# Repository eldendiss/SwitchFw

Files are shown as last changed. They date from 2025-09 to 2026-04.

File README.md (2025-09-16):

# AVR HV Flyback & Geiger-Müller Tube Detector

A high-voltage flyback power supply controller with integrated Geiger-Müller tube detector, featuring 4 selectable voltage ranges and I²C communication interface.

## Overview
This project implements an AVR-based controller for a high-voltage flyback power supply system designed for Geiger-Müller tube applications. The system provides precise voltage regulation across 4 selectable ranges, pulse counting capabilities, and remote control via I²C communication.

### Key Features
- High-Voltage Flyback Control: PWM-controlled flyback transformer with feedback regulation
- 4 Voltage Ranges: Relay-switched voltage ranges for different GM tube requirements
- Geiger Pulse Detection: Hardware pulse counting with debouncing and filtering
- I²C Slave Interface: Remote configuration and monitoring via I²C protocol
- Fault Protection: Overvoltage detection, current limiting, and safety shutdowns
- EEPROM Storage: Persistent configuration storage with wear leveling
- Status Indication: LED indicators for system status and fault conditions

## Hardware Architecture
### Core Components
- MCU: ATmega328P (TQFP-32) running at up to 20MHz
- Power Stage: IRF540N N-channel MOSFET with TC4420 gate driver
- Voltage Reference: LM4040 2.5V precision shunt regulator
- Amplifiers: LM321 operational amplifiers for signal conditioning
- Protection: SMAJ150A transient voltage suppressor
- Power Supply: LM317 adjustable linear regulator for 5V rail

### Voltage Range Switching
Four relay-controlled voltage ranges provide flexibility for different GM tube types.

## Pin Configuration
### I²C Communication
- **SDA**: PC4
- **SCL**: PC5
- **Default address**: 0x2A

### Control Outputs
- **PWM**: PB1 - Flyback MOSFET
- **Range Relays**: PD4, PD5, PB6, PB7 - Voltage range selection
- **Status LEDs**: PC2, PC3 - System status indication

### Analog Inputs
- **Feedback**: PC0 - Voltage feedback from HV output
- **Current Sense**: PC1 - Shunt current measurement

### Digital Inputs
- **Enable**: External enable signal
- **Range Select**: Hardware range selection inputs

### Programming interface
- **ISP header**: MISO (PB4), MOSI (PB3), SCK (PB5), RESET (PC6)

## Firmware Features

### PWM Control System
- **Frequency**: 31.25 kHz (configurable)
- **Resolution**: 8-bit (256 steps)
- **Duty Cycle Range**: 0-20% (safety limited)
- **Control Loop**: 1 kHz PI controller with derivative feedback

### Voltage Regulation
- **Feedback**: 10-bit ADC with 8× averaging
- **Setpoint Resolution**: ~1V steps (depending on range)
- **Regulation Accuracy**: ±1% typical
- **Response Time**: <100ms to 90% of setpoint
### Fault Protection
- **Overvoltage**: Programmable trip and clear thresholds per range
- **Overcurrent**: Hardware comparator with cycle-by-cycle limiting
- **Watchdog**: Hardware and software watchdog protection
### Geiger Pulse Detection
- **Input Conditioning**: Hardware debouncing and noise filtering
- **Count Resolution**: 32-bit counters
- **Rate Calculation**: CPS (counts per second) and CPM (counts per minute)
- **Dead Time Compensation:** Configurable dead time correction

## I²C Protocol
### Register Map
|Address |Name |Type |Decsription |
|---|---|---|---|
|0x00-0x01  |FB_SET_CNT |R/W |Active feedback setpoint (counts)  |
|0x02-0x03  |FB_OV_TRIP_CNT |R/W |Active overvoltage trip threshold  |
|0x04-0x05  |FB_OV_CLEAR_CNT |R/W |Active overvoltage clear threshold |
|0x06-0x0D  |FB_SET_CNT_TAB |R/W |Per-range setpoint table (4×u16) |
|0x0E-0x15  |FB_OV_TRIP_TAB |R/W |Per-range OV trip table (4×u16) |
|0x16-0x1D  |FB_OV_CLEAR_TAB |R/W |Per-range OV clear table (4×u16) |
|0x20 |RANGE_REQ |W |Range selection request (0-3) |
|0x21 |RANGE_SRC |R/W |Range source (0=HW, 1=I2C, 2=AUTO) |
|0x40 |CMD |W |Command register |
|0x50-0x57  |STATUS |R |8-byte status block |

### Commands (0x40)
- **0x01**: Save configuration to EEPROM
- **0x02**: Reset controller to PRECHARGE state

### Status Block (0x50-0x57)

```c
struct {
    uint8_t  run_state;     // Current controller state
    uint8_t  fault_code;    // Active fault conditions
    uint16_t fb_counts;     // Current feedback (ADC counts)
    int16_t  dcounts;       // Feedback derivative
    uint8_t  active_range;  // Currently selected range (0-3)
    uint8_t  range_busy;    // Range switching in progress
} status;
```

## Software Architecture
### Control States
- **PRECHARGE**: Soft-start phase with fixed low duty cycle
- **PI_CONTROL**: Closed-loop voltage regulation
- **PFM_HOLD**: Closed-loop voltage regulation
- **FAULT**: Safe shutdown with fault indication

### Main Control Loop (1 kHz)
1. **ADC Sampling**: Read feedback voltage with 8× averaging
2. **Fault Detection**: Check overvoltage and overcurrent conditions
3. **PI Controller**: Calculate required PWM duty cycle
4. **Range Management**: Handle relay switching with stability checks
5. **Pulse Counting**: Process Geiger tube pulses
6. **I²C Service**: Handle configuration updates and status requests

### Safety Features
- **Duty Cycle Limiting**: Hardware and software duty cycle caps
- **Fault Latching**: Persistent fault states requiring explicit reset
- **Graceful Degradation**: Automatic power reduction under fault conditions
- **Watchdog Protection**: System reset on firmware lockup

## Configuration and Calibration
### Voltage Scaling
The system uses a configurable voltage divider to scale HV output to ADC range:
- **Full Scale**: 1077.5V = 1023 ADC counts (default)
- **Resolution**: ~1.05V per ADC count
- **Calibration**: Adjustable via I²C configuration

### Range-Specific Parameters
Each voltage range has independent configuration:

- **Setpoint**: Target voltage in ADC counts
- **OV Trip**: Overvoltage fault threshold
- **OV Clear**: Overvoltage recovery threshold

### EEPROM Layout
Configuration is stored in EEPROM with wear leveling:

- **Slot Size**: 128 bytes per configuration
- **Wear Leveling**: Automatic slot rotation
- **CRC Protection**: 16-bit CRC for data integrity
- **Default Recovery**: Automatic fallback to safe defaults

## Safety Considerations
### Electrical Safety
- **High Voltage Warning**: Output voltages up to 1000V present electrocution hazard
- **Isolation**: Maintain proper isolation between HV and control circuits
- **Interlocks**: Implement appropriate safety interlocks for enclosure access
- ****:

### Operational Safety
- **Fault Monitoring**: Always monitor fault status during operation
- **Emergency Shutdown**: Implement external emergency stop capability
- **Thermal Management**: Ensure adequate cooling for power components

## Troubleshooting

### Common Issues
#### No HV Output
- Check enable signal
- Verify PWM generation on PB1
- Check MOSFET gate drive
- Verify transformer connections

#### I²C Communication Errors
- Verify bus pull-up resistors
- Check address conflicts
- Monitor bus timing
- Verify power supply stability

## Development and Programming
### Build Environment
- **Toolchain**: AVR-GCC with AVR-LibC
- **IDE**: PlatformIO
- **Programmer**: ISP programmer (USBasp, AVR Dragon, etc.)

## License
This project is licensed under a **Non-Commercial License**.  
- ✅ Free for personal, educational, and research use.  
- ❌ Commercial use, redistribution for profit, or inclusion in commercial products is prohibited without written permission.  
See [LICENSE](./LICENSE) for details.

⚠️ WARNING: This device generates potentially lethal high voltages. Only qualified personnel should operate, maintain, or modify this equipment. Always follow proper safety procedures when working with high-voltage systems.

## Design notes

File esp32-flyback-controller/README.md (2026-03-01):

# Flyback PSU & Geiger Counter ESP-IDF Driver

ESP-IDF drivers for:
- an **AVR flyback HV PSU** (I²C, 4 ranges, status/commands), and
- a **Geiger pulse counter** using the ESP32 RMT RX peripheral.

Works on ESP-IDF v5+.

## Overview

- **Flyback PSU driver (`flyback_psu`)**: Configure per-range setpoints/OV thresholds, select ranges (HW/I²C/AUTO), read 8-byte status, and issue SAVE/RESET commands. Counts↔volts helpers included.
- **Geiger counter driver (`geiger_counter`**: Counts tube pulses with RMT RX. Filters glitches by minimum pulse width. Provides **CPS, CPM (rolling 60 s)**, and **total**. Thread-safe getters.
- **Example application (`main`)**: Demonstrates how to initialize and use both drivers together, cycling through PSU voltage ranges and logging Geiger counts.

---

## Features

### Flyback PSU

- I²C master init/reuse, configurable clock.
- Range source control: HW / I²C / AUTO.
- Program per-range set, OV trip, OV clear (counts or volts).
- Read compact STATUS: run_state, fault_code, fb_counts, dcounts, active_range, busy.
- SAVE_CONFIG, RESET_CTRL commands.
- Helpers: volts↔counts, set profiles, wait-until-idle.

### Geiger Counter

- RMT RX capture with **min pulse width** filter (ns).
- Configurable **active level** (high/low), **resolution** (Hz), buffer size.
- Thread-safe **get_total(), get_cps(), get_cpm()**.
- Internal task processes RX buffers (zero-copy on symbols).

---

## Hardware Requirements

- ESP32/ESP32-Sx/Cx with ESP-IDF v5+
- I²C wiring to AVR PSU at 0x2A (pull-ups required)
- Tube pulse output routed to an ESP32 GPIO
- CMake build (component-based)

---

## Getting Started

### 1. Clone and Setup ESP-IDF

Follow the official ESP-IDF setup guide:

[ESP-IDF Programming Guide](https://docs.espressif.com/projects/esp-idf/en/latest/esp32/get-started/)

### 2. Add Flyback PSU and Geiger Counter Drivers

Include the provided driver source files (`flyback_psu.h/c`, `geiger_counter.h/c`) in your project.

### 3. Example Application

The example demonstrates:

- Initializing the flyback PSU over I²C.
- Setting voltage setpoints and overvoltage thresholds.
- Forcing I²C control of the active voltage range.
- Initializing the Geiger counter on a GPIO pin.
- Cycling through the four voltage ranges, holding each for 60 seconds.
- Logging PSU status and Geiger counts every second.

---

## API Usage

### Flyback PSU

#### Initialization

```c
flyback_psu_t psu;
ESP_ERROR_CHECK(flyback_psu_init(&psu, I2C_NUM_0, SDA_GPIO, SCL_GPIO, 10000 /* 10 kHz */, 0x2A));
flyback_psu_set_fullscale(&psu, 1077.5f); // 1023 counts == 1077.5 V
```

#### Set Range Source to I²C

```c
ESP_ERROR_CHECK(flyback_psu_set_range_source(&psu,  FLYBACK_RANGE_SRC_I2C));
```

#### Set Voltage Setpoints (volts)

```c
const float V[4] = {200, 500, 700, 900};
uint16_t C[4];
for (int i=0;i<4;i++) C[i] = flyback_psu_volts_to_counts(&psu, V[i]);
ESP_ERROR_CHECK(flyback_psu_set_table_counts4(&psu, C));

// Trip/Clear @ +10% / +5%
for (int i=0;i<4;i++){
  ESP_ERROR_CHECK(flyback_psu_set_trip_counts(&psu,  i,
     flyback_psu_volts_to_counts(&psu, V[i]*1.10f)));
  ESP_ERROR_CHECK(flyback_psu_set_clear_counts(&psu, i,
     flyback_psu_volts_to_counts(&psu, V[i]*1.05f)));
}
// Optional: ESP_ERROR_CHECK(flyback_psu_send_command(&psu, FLYBACK_CMD_SAVE_CONFIG));
```

#### Start the Geiger counter
```c
geiger_counter_t gc = {0};
ESP_ERROR_CHECK(geiger_counter_start(&gc,
    GPIO_NUM_4,          // pulse input GPIO
    true,                // active-high pulses
    20000000,            // 20 MHz resolution (50 ns tick)
    1000,                // ≥1 µs min pulse width
    2048));              // RX symbol buffer

```

#### Select Active Range

```c
ESP_ERROR_CHECK(flyback_psu_select_range(&psu, range_index));
ESP_ERROR_CHECK(flyback_psu_wait_idle(&psu, 3000, 10)); // wait for relay switch
```

#### Read Status

```c
flyback_psu_status_t status;
if (flyback_psu_read_status(&psu, &status) == ESP_OK) {
    float feedback_volts = flyback_psu_counts_to_volts(&psu, status.fb_counts);
    // Use status fields as needed
    ESP_LOGI("PSU","st=%u fault=%u fb=%u(%.1fV) d=%d r=%u busy=%u",
             s.run_state, s.fault_code, s.fb_counts, v, (int)s.dcounts,
             s.active_range, s.range_busy);
}
ESP_LOGI("GEIGER","CPS=%.1f CPM=%.1f Total=%llu",
           geiger_counter_get_cps(&gc),
           geiger_counter_get_cpm(&gc),
           (unsigned long long)geiger_counter_get_total(&gc));
  vTaskDelay(pdMS_TO_TICKS(1000));
```

### Geiger Counter

#### Initialization
```c
static geiger_counter_t gc;
ESP_ERROR_CHECK(geiger_counter_start(&gc, TUBE_GPIO, TUBE_ACTIVE_HIGH, 20000000, 1000, 2048));
```

#### Get Counts

```c
float cps = geiger_counter_get_cps(&gc);   // Counts per second (delta)
float cpm = geiger_counter_get_cpm(&gc);   // Counts per minute (rolling 60s)
uint64_t total = geiger_counter_get_total(&gc); // Total counts since start
```

#### Stop Counter
```c
ESP_ERROR_CHECK(geiger_counter_stop(&gc));
```

## Example output
```
I (1234) example: Selecting range 0 -> target voltage ~200.0 V (counts=190)
I (1235) example: PSU status: state=1 fault=0 fb_counts=185 (~198.5 V) dcounts=0 active_range=0 busy=0
I (1235) GEIGER: Counts: CPS=5.0  CPM=300.0  Total=1500
...
```

## Notes & Best Practices
- **I²C speed:** Start at **10 kHz** (robust on long harnesses). If wiring is short/clean, 100–400 kHz is fine.
- **Range arbitration:**
    - `AUTO`: hardware pins control until the first I²C request, then I²C takes over.
    - If your front panel uses the HW pins, prefer AUTO so remote control can still take over.
- **STATUS → volts:** `V ≈ fb_counts * (fullscale / 1023.0)`, default fullscale **1077.5 V**.
- **RMT sizing:**
    - `resolution_hz = 20 MHz` gives 50 ns ticks; good for 2–5 µs pulses.
    - `min_pulse_ns`: start with 1000 ns (rejects narrow noise).
    - `buf_symbols`: 1024–2048 typical; increase if you expect high CPM or bursts.
- **Threading**:
    - RMT RX runs a task; getters use a mutex; safe from multiple tasks.
    - Avoid calling `geiger_counter_stop` from ISR context.

- The Geiger counter uses a dedicated FreeRTOS task and RMT peripheral; ensure sufficient stack size and priority.
- Use flyback_psu_send_command() to save configuration to EEPROM or reset the controller if needed.
- The example cycles through all four voltage ranges, holding each for 60 seconds, printing status and counts every second.

## Troubleshooting
- **I²C timeouts**
    - Check address `0x2A`, pull-ups, and grounds. Drop bus to **10 kHz** first.
- **STATUS never idle (`busy=1`)**
    - Mechanical relays need time; ensure `flyback_psu_wait_idle()` poll interval ≥ 10 ms and timeout ≥ 3 s.
- **OV faults**
    - Trip/clear thresholds too tight for the measured divider scaling. Re-measure HV and adjust counts.
- **Few/no counts**
    - Pulse polarity mismatch (`active_high`). Increase `min_pulse_ns` if noise, decrease if valid pulses are ~1–2 µs but get filtered.

## License
This project is licensed under a **Non-Commercial License**.  
- ✅ Free for personal, educational, and research use.  
- ❌ Commercial use, redistribution for profit, or inclusion in commercial products is prohibited without written permission.  
See [LICENSE](./LICENSE) for details.

## References
- [ESP-IDF Programming Guide](https://docs.espressif.com/projects/esp-idf/en/latest/esp32/)
- [ESP32 RMT Peripheral](https://docs.espressif.com/projects/esp-idf/en/latest/esp32/api-reference/peripherals/rmt.html)
- AVR flyback PSU firmware documentation

## Notes
Lite: SDA=21, SCL=22
Big: SDA=22, SCL=21

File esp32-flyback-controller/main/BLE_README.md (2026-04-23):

# RaSens BLE Documentation

## UUID

We use 128-bit Vendor UUID - 16 bit UUIDs are reserved for SIG approved devices.

Device base UUID is assigned at random per device type, except for last 2 bytes. For example:
- Base: ```704d43a7-dd07-49f1-9818-8ca1364e0000```

Each service characteristic uses the last 2 bytes for identification. For simplicity in this documetation, we will only specify the last 2 bytes appended to base UUID, e.g. ```...0001``` translates to ```704d43a7-dd07-49f1-9818-8ca1364e0001```

```
0000 - Base UUID
    0010 - Provisioning Service
        0011 - SSID Characteristics
        0012 - Password Characteristics
        0013 - MQTT Server Characteristics
        0014 - MQTT Port Characteristics
        0015 - Access Token Characteristics
        0016 - Command Characteristics
        0017 - Status Characteristics
    0020 - Configuration Service
        0021 - Interval Characteristics    
        0022 - Range Characteristics 
        0023 - Set Voltage Characteristics      
        0024 - Coefficients Characteristics 
```

Each characteristics also has permissions and properties, see BLE documentation for more info about these. There is also an option of encrypted read/write, which allow operation only after devices are bonded.
Test

Defined services (later will be extended further):

---
### Provisioning Service

- Provision wifi credentials / MQTT server
- Provisioning is confirmed by writing a command
- Allows notifications on status
- UUID: ```0010```

#### SSID
- UUID: ```0011```
- Properties: Write
- Permissions: currently only W, in the future consider encrypted W
- Do not expose as Read in production
- Data: UTF-8, max 32 bytes

#### Password
- UUID: ```0012```
- Properties: Write
- Permissions: currently only W, in the future consider encrypted W
- Do not expose as Read in production
- Data: UTF-8, max 63 bytes

#### MQTT Server
- UUID: ```0013```
- Properties: Read/Write
- Permissions: R/W
- Data: UTF-8, max. 63 bytes

#### MQTT Port
- UUID: ```0014```
- Properties: Read/Write
- Permissions: R/W
- Data: uint16

#### Access Token
- UUID: ```0015```
- Properties: Write
- Permissions: currently only W, in the future consider encrypted W
- Data: UTF-8, max. 24 bytes

#### Apply/Command
- UUID: ```0016```
- Properties: Write
- Permissions: W
- Data: 1 byte
    - ```0x01``` - Apply (attempt Wifi+MQTT connect)
    - ```0x02``` - Disconnect / Clear
    - ```0x03``` - Save (do not connect instantly)

#### Status
- UUID: ```0017```
- Properties: Read + Notify
- Permissions: R
- Data: 8 byte array
    - ```device_status```
    - ```wifi_status```
    - ```mqtt_status```
    - ```err_code```
    - ```wifi_rssi```
    - ```reserved[3]```

---
### Configuration Service
- Set up device parameters
- UUID: ```0020```

#### Measurement Interval
- UUID: ```0021```
- Properties: Read/Write
- Permissions: R/W
- Data: unsigned word (4 bytes) - interval

#### Selected Range
- UUID: ```0022```
- Properties: Read/Write
- Permissions: R/W
- Data: 1 byte - range

#### Set Voltage
- UUID: ```0023```
- Properties: Read/Write
- Permissions: R/W
- Data: 8 bytes
    - 2 bytes - V0
    - 2 bytes - V1
    - 2 bytes - V2
    - 2 bytes - V3

#### Coefficients
- UUID: ```0024```
- Properties: Read/Write
- Permissions: R/W
- Data: 16 bytes
    - 4 bytes - c0
    - 4 bytes - c1
    - 4 bytes - c2
    - 4 bytes - c3

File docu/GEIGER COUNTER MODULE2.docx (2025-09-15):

# GEIGER COUNTER MODULE

Radiation Detection Board

Vesion: 2.0
Sep 14, 2025

DATASHEET & USER MANUAL

# Introduction

This system is a two-board Geiger tube PSU and front-end:

- Switcher — ATmega328P-based flyback controller (PWM, OC/OV protection, burst-hold regulation, I²C slave).
- MainBorad — transformer, rectifier, HV divider (4.3 MΩ/10 k), range relays/connectors, fast pulse comparator to ESP32.

Firmware supports 4 channels (ranges), per-channel voltage/OV thresholds over I²C with EEPROM wear-levelled storage. Danger: high voltage. See Safety.

## Features

- 250–1000 V high-voltage output with burst/skip hold to minimize input power at steady state.
- 4 channels selectable via RANGE1:RANGE0; break-before-make switching with PWM inhibited.
- I²C slave: set/get per-channel Vtarget, OVtrip, OVclear; set/get control tuning; save/load defaults; wear-levelled persistence.
- Protections: Over-current via analog comparator; over-voltage latch with hysteresis; CRC-32 app integrity check at boot.
- Status LEDs: OK = lit during burst/hold; FAULT = coded blinks (configurable).

## Safety Notice

⚠️ High Voltage Warning:
This module generates high voltages up to 1000 V, which can pose a serious electric shock hazard. Always handle the board with care during operation, and ensure the system is powered down before adjusting or probing high-voltage areas. Relays switch HV paths: never hot-switch channels under load; firmware enforces break-before-make delay.

⚠️ Discharge Capacitors Before Handling:
The output capacitor (typically 1 µF or larger) can retain dangerous voltage levels even after the power is disconnected. Always ensure high-voltage output lines are properly discharged before touching or handling the circuit.

⚠️ Use Proper Isolation:
Do not operate the module on conductive or metallic surfaces. Use appropriate insulating spacers and enclosures if the module is installed in confined spaces or near user-accessible areas.

⚠️ Intended for Qualified Personnel:
This device is intended for use by individuals with a basic understanding of electronics and high-voltage safety. Improper use may result in injury, equipment damage, or exposure to harmful voltages.

# System Overview

## Block Diagram

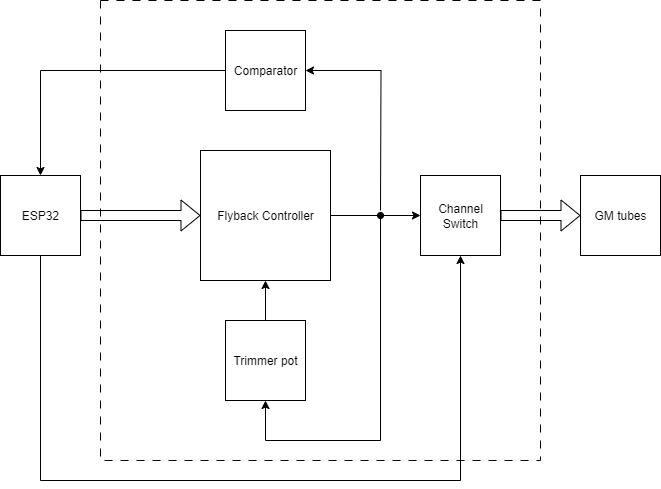
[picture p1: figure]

At the core of the module is a programmable high-voltage power supply based on the LT3751 flyback controller, capable of generating up to 500–600 V DC. The system features four independent output channels, each with its own voltage control and feedback path. Only one channel is active at a time.

Operating principle:

1. Startup: Ramp to setpoint with limited duty. This slowly charges output capacitor to target voltage.
2. Voltage Regulation: Burst/skip regulation phase to cut average input power.
3. Radiation Detection: When the active GM tube detects an event, it generates a discharge across the tube, which presents as an intermittent short-circuit.
4. Pulse Conditioning: The analog pulse is filtered and shaped by the comparator and output as a clean ~3–5 µs logic pulse.
5. Microcontroller Processing: The ESP32 receives the pulse on a GPIO pin and handles counting, timing, and display/output functions.

# Electrical Specification

This section outlines the key electrical parameters of the Geiger Counter Module, including operating conditions, signal characteristics, tube compatibility, and timing performance. All values are nominal unless otherwise stated.

## Operating Voltage and Current

Parameter | Min | Typ | Max | Unit | Notes
Input voltage | 8 | 12 | 20 | V | Regulated input recommended
Input current (idle) | - | 56 | 70 | mA | Average
Input current (charging) | - | 120 | 200 | mA | Average
Output voltage (HV) per channel | 250 | - | 1000 | V | Individually adjustable for each channel
Channels | - | 1 | 4 | - | One channel active at any time

## Output Pulse Characteristics

Parameter | Value | Unit | Notes
Pulse type | 3.3 | V | Digital (SQW). Selectable by JP3
Pulse Width | ~ 2-5 | µs | Depends on GM tube used
Pulse Rise/Fall Time | < 10 / <500 | ns | Typ.

## Geiger Tube Compatibility

Parameter | Value | Unit | Notes
Tube Operating Voltage | 250-1000 | V | Adjustable via I2C per channel.

## Timing and Performance Metrics

Metric | Value | Unit | Notes
HV Rise Time | ~5 | s | Depends on input supply & load
Max Count Rate | > 10000 | CPS | Limited by GM tube dead time
ESP32 Max Pulse Rate | > 25000 | CPS | ESP32 GPIO + interrupt
Output Voltage Accuracy | ±1–5 | % | Typ.

# Hardware Description

The Geiger Counter Module integrates all key hardware required to operate and interface a Geiger-Müller tube with a modern microcontroller. This section details the roles of the high-voltage supply, tube biasing, signal conditioning, and digital interfacing.

## SwitchBoard (ATmega328P)

The high-voltage required for Geiger-Müller tube operation is generated using the LTC3751, a dedicated high-voltage flyback controller. The converter steps up the 5 V input to user-selectable voltages in the 250–550 V range.

Key Features:

- Timer1 PWM @ 20 kHz drives MOSFET gate (OC1A).
- Analog comparator: + = 1.1 V bandgap, − = AIN1; falling edge IRQ kills PWM for the cycle.
- ADC0 samples buffered divider; EMA filtering; PI(+D) regulator and burst-hold.
- I²C slave interface for config + status.

## MainBoard

- Transformer + rectifier + HV reservoir.
- 4.3 MΩ / 10 k divider to ADC.
- 4 range relays select active output channel

## Geiger Tube Driver and Biasing

The HV output of the active channel is fed to the anode of the Geiger-Müller tube. A series resistor (2 MΩ) limits discharge current and ensures proper tube operation. The cathode is connected to GND.

Notes:

- The output capacitor (typically 1 µF) stores energy for fast HV rise
- Proper output voltage selection ensures tube safety and long life
- Only one tube is biased at any time

## Pulse Detection

Ionizing radiation causes a brief discharge in the GM tube, resulting in a sharp voltage drop across the load resistor. This analog signal is sensed by the LM311 comparator, which outputs a clean digital pulse.

Comparator Configuration:

- Input signal filtered with a small RC network
- Reference voltage from the LM311’s internal 1.182 V REF pin
- Output swing from GND to 3.3 V.
- Hysteresis pin tied to REF or adjusted for noise immunity

Pulse output is stable, reproducible, and ideal for digital counting. A typical output pulse is ~2–5 µs wide and ~3.3 V high, active LOW.

# Pinout and Connectors

## Board Pin Description

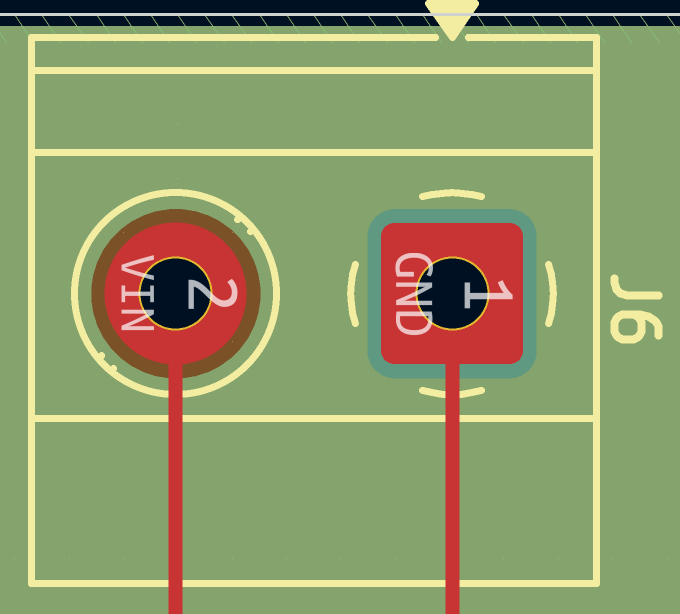
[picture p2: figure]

J6: Input Voltage Connector

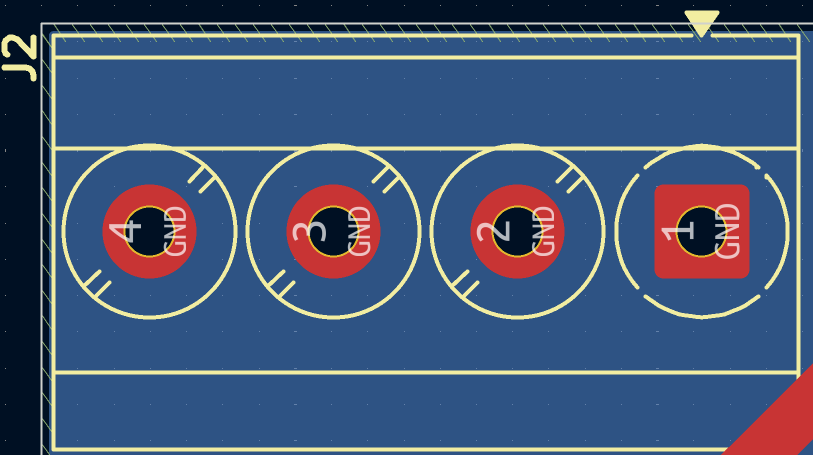
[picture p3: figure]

GND: GM tube cathode connector

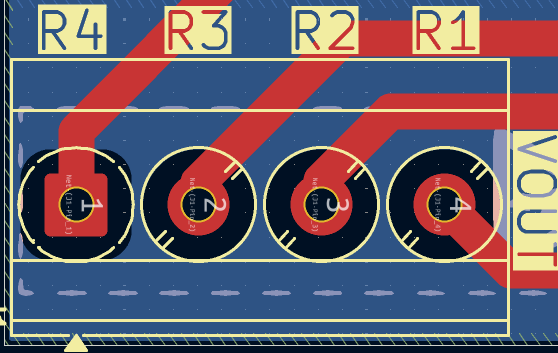
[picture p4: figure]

VOUT: GM tube anode connector

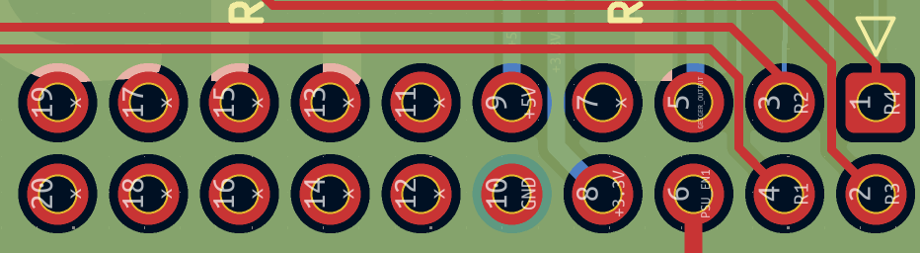
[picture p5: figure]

J5: IDC GPIO Connector

IDC Connector Pinout
Pin Number | Pin Name | Description
4 | R1 | Range 1 switch GPIO. HIGH = Selected
3 | R2 | Range 2 switch GPIO. HIGH = Selected
2 | R3 | Range 3 switch GPIO. HIGH = Selected
1 | R4 | Range 4 switch GPIO. HIGH = Selected
6 | ONOFF | Regulator Enable/Soft Start Pin, see below for more information. HIGH = ON
5 | GEIGER_OUT | Pulse Output Pin
8 | 3.3V | 3.3 V power supply. Can be left NC when using 5V logic level
9 | 5V | 5 V power source. Supplied by internal regulator from regulator input.
10 | GND | Ground
7, 11, 12, 13, 14, 15, 16, 17, 18, 19, 20 | NC | Not used

## Jumper Settings

Jumper | Description
TP1 | Feedback signal testpoint, before LP filter
TP2 | Feedback signal testpoint, after LP filter
JP3 | Logic level jumper, selects 5V or 3.3V logic level
JP4 | Not used

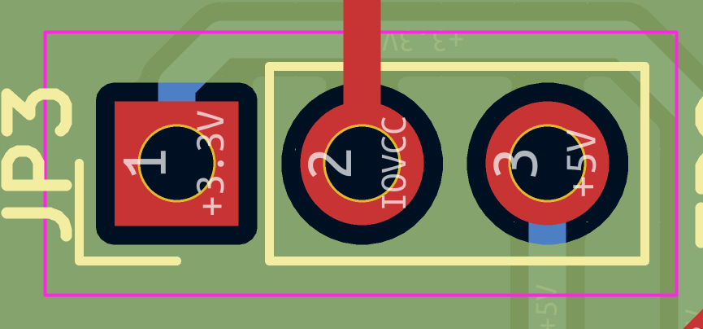
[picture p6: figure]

JP3 signal specification. Short 1-2 to enable 3.3V logic level, or 2-3 to set 5V. Do not leave floating.

# Getting Started

This section explains how to safely power the module, connect a Geiger-Müller tube, and interface the system with an ESP32 microcontroller. Proper startup and shutdown procedures are essential to avoid overcurrent or failed HV startup, especially at higher output voltages.

## Powering the Module

The module is powered from a regulated 12 V DC supply (adapter, lab PSU, or battery). Input current during high-voltage ramp-up can reach > 3A in peak (<1ms), so ensure the power source has enough capacitance to cover this surge.

To prevent inrush and enable reliable HV charging at high voltages, the module requires a soft start sequence:

⚡ Soft Start Procedure

- ON/OFF pin is connected to the CHARGE input of the LT3751
- Instead of applying logic high constantly, the ONOFF pin should receive a series of short PWM-like pulses with gradually increasing duty cycle

Recommended Soft Start:

- Pulse every 10 ms, starting from ~10% duty (1 ms width)
- Increase duty linearly to ~100% over ~1 second
- After 1 s, leave ONOFF pin permanently HIGH (5 V or 3.3 V depending on system)

This allows the output capacitor (e.g., 1.1 µF) to charge more gradually, avoiding high peak current and startup failure — especially when output is set above 400 V or the input source is a current-limited lab supply.

## Connecting the Geiger Tube

Each of the 4 channels has a dedicated HV output path for a single Geiger-Müller tube. Only one tube should be active at a time.

Connection Guidelines:

- Anode (positive side) → Channel HV output screw-terminal
- Cathode (negative side) → GND screw-terminal
- Optionally, a quench capacitor (e.g., 10–100 pF) between cathode and GND can improve pulse shape

⚠️ Make sure the HV output is disabled (ONOFF LOW) before connecting/disconnecting tubes.

## ESP32 Integration Example

The LTC1440 provides a clean digital pulse on each radiation event. This is ideal for use with ESP32 interrupts.

Remember to set logic voltage via JP3 before powering up the device.

Example Wiring:

GM Board | ESP32
GEIGER_OUT | GPIO4
ONOFF | GPIO5
GND | GND
3.3V | 3.3V must be able to source current

🌀 Switching Channels (Voltage Ranges)

To change the active channel:

1. Disable output: Set ONOFF = LOW
2. Switch range: Set GPIOs to new channel
3. Soft-start ONOFF again (see above)

⚠️ Failing to disable before switching may result in overcurrent or startup failure.

# Calibration and Testing

This section describes how to validate module functionality and fine-tune each channel’s high-voltage output. Proper testing ensures accurate tube operation and reliable pulse detection.

## Verifying Pulse Output

To confirm correct operation of the pulse detection circuit:

1. Power up the module using the soft-start sequence
2. Ensure a Geiger-Müller tube is connected to the active channel
3. Use a known radioactive source or wait for background radiation
4. Connect the OUT pin (via jumper TP1, TP2 or GPIO header) to an oscilloscope or ESP32 GPIO
5. Observe pulses:
  - Voltage level: ~3.3 V
  - Width: ~20–30 µs
  - Rate: Depends on radiation intensity (typically 10–100 CPM for background)

Tip: Use a 10× scope probe and confirm clean rising edges. ESP32 can detect pulses via GPIO interrupt if signal is ~20 µs or longer.

## Measuring High Voltage

To check output voltage of a specific channel:

⚠️ Safety First

- Discharge output capacitor before touching any HV parts
- Use an appropriate high-voltage probe (e.g., 1:100)

Procedure:

1. Set the ONOFF to enable output (see Powering the module section)
2. Use a high-voltage probe to measure across HV output and GND of the active channel
3. Confirm voltage matches expected value (e.g., 400–500 V)

For relative comparison or rough estimates, you can use a high-value voltage divider (e.g., 100 MΩ + 1 MΩ) to step down to multimeter-safe levels.

## Adjusting Output Voltage via POT

Each channel includes a trimmer potentiometer to set the target high voltage.

Adjustment Steps:

1. Locate the trimpot for the desired channel
2. Use a ceramic or insulated screwdriver to rotate:
- Clockwise → Increase output voltage
- Counter-clockwise → Decrease output voltage
3. Measure HV with a scope or HV probe
4. Repeat steps 2-3 to fine-tune

⚠️ Important Safety & Handling Notes:

- ⚠️ The trimpot is extremely sensitive — small adjustments can change the output by tens of volts
- ⚠️ Be very careful while adjusting the HV output while regulator is active — Over-adjusting risks arc-over, damage to surrounding components, or personal injury
- ⚠️ Always disable HV and wait for discharge before touching the board
- Over-adjusting the trimpot may cause the output voltage to exceed the safe limits of the flyback diode or transformer, possibly creating spark gaps or catastrophic failure

If unsure, stay within 300–550 V range per channel unless properly rated parts and layout clearances are verified for 550+ V.

Allow the output to stabilize for a few seconds before taking readings.

# Troubleshooting

This section provides solutions to common problems encountered during setup and operation of the Geiger Counter Module. Causes are listed from most probable one to the least.

## No Pulses Detected

Symptom: No pulses on scope or ESP32

Possible cause | Solution
Tube not connected properly | Verify tube polarity: anode to HV, cathode to GND
Voltage too low for used GM tube | Increase HV output voltage
No radiation source or background too low | Use a known radiation source
GEIGER_OUT not connected to ESP32 properly | Check wiring, use scope to verify signal at OUT pin
LTC1440 faulty | Replace the component
Faulty tube or expired GM tube | Try a known working tube

## HV Not Starting

Symptom: Output voltage remains 0 V or doesn’t hold required level.

Possible cause | Solution
Soft-start not implemented | Apply increasing PWM pulses on ONOFF pin for ~1s
No input current spike | Increase HV output voltage
Output voltage set too high | Dial back the trimpot (very carefully!) and try again
Weak PSU | Try powering from battery or use PSU with higher current limit
Faulty flyback diode or transformer | Replace the component

# Mechanical Information

This section outlines the physical characteristics of the Geiger Counter Module, including board size, mounting options, and electrical interface details.

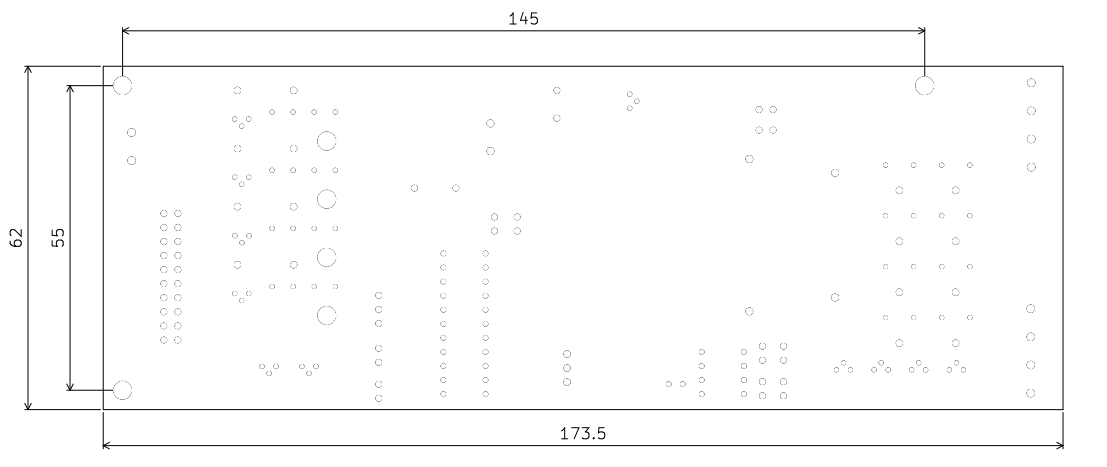
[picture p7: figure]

## Board Dimensions

Parameter | Value
Width | 173.5 mm
Height | 62 mm
PCB thickness | 1.6 mm

📏 Measurements are approximate and may vary slightly by revision.

## Mounting Holes

The PCB includes three corner mounting holes for secure installation in enclosures or onto standoffs.

Parameter | Value
Hole diameter | 3.2 mm
Mounting pattern | 145 x 55 mm
Compatible Hardware | M3 screws or standoffs

🛠 Ensure adequate standoff height to maintain HV isolation from the mounting surface.

## Connector Types

Connector | Description | Pin Count | Voltage Level
J6 | 5.08mm TBlock | 2 | 12V typ.
VOUT, GND | 5.08mm TBlock | 4 | Up to 1000 V
J5 | 2x10 2.54mm IDC | 20 | 3.3-5 V

# Revision History

Revision | Date | Author | Description
V1.0 | 2025-07-30 | DV | Initial release — full system documentation including electrical, mechanical, and software interface

# Appendix A: Safety Notices and Disclaimer

⚠️ Electrical Hazard Notice
This product operates at potentially dangerous high voltages. Contact with live components may cause electric shock, burns, or death. Always ensure the system is powered down and fully discharged before performing any modifications or maintenance.

⚠️ Usage Restriction
This device is not certified for use in medical, life-support, or safety-critical systems. It is intended for research, prototyping, or educational use by qualified individuals only.

⚠️ User Responsibility
The end user is responsible for ensuring safe operation, proper insulation, and compliance with all relevant local electrical codes, safety standards, and handling procedures.

⚠️ Product Modification
Unauthorized modifications, including changing resistor values, output voltage range, or firmware behavior, may result in unsafe operation. Do so only if you understand the full implications.

📝 Document Accuracy
While all efforts have been made to ensure the accuracy of this document, it may contain technical inaccuracies or typographical errors. Always cross-check critical specs against the official datasheets of referenced ICs (e.g., LTC3751, LTC1440, ESP32).

# Appendix B: Reference Datasheets

Component | Manufacturer | Notes / Link
LT3751 | Analog Devices | AD (https://www.analog.com/media/en/technical-documentation/data-sheets/lt3751.pdf)
LTC1440 | Analog Devices | AD (https://www.analog.com/media/en/technical-documentation/data-sheets/144012fd.pdf)
GA3460-BL | Coilcraft | Coilcraft (https://www.coilcraft.com/getmedia/eb987d97-6bee-4e60-8a64-a66d4e6e447b/ga3459.pdf)

2 ⚠️Danger: High Voltage. Handle with care.

3MP projekt s.r.o. ul.Slov.nár.povstania 22 920 01 Hlohovec Slovak Republic

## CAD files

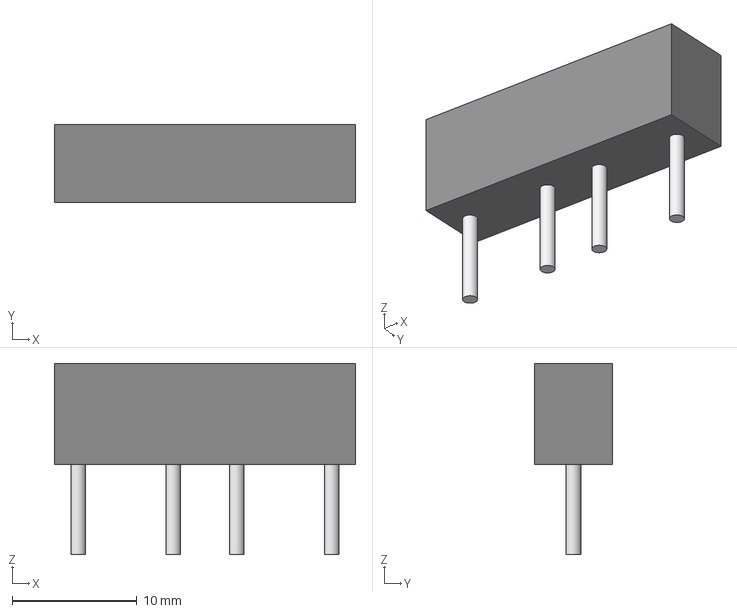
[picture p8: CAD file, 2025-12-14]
pcb/RaSens/3dshapes/RLA4_SHV_SME.step
24.1 x 6.22 x 15.3 mm

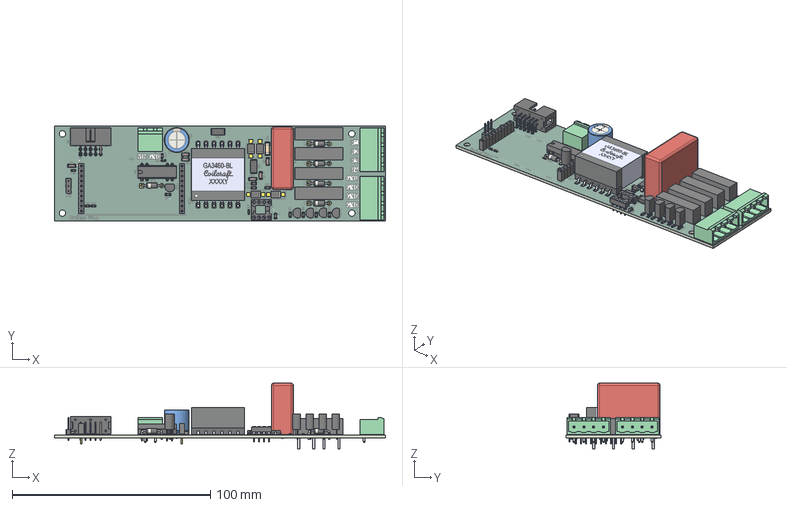
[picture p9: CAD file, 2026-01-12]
pcb/RaSens/RaSens.step
167.0 x 48.0 x 33.2 mm
R_0603_1608Metric x 5
C_1206_3216Metric x 6
D_DO-41_SOD81_P10.16mm_Horizontal x 5
R_0805_2012Metric x 8
TO-92L_Inline x 5
C_0805_2012Metric
D_SMB x 4
R_MELF_MMB-0207
5-535541-8_TYC x 2
PhoenixContact_MSTBA_2,5_2-G-5,08_1x02_P5.08mm_Horizontal
PhoenixContact_MSTBA_2,5_4-G_1x04_P5.00mm_Horizontal x 2
RLA4_SHV_SME x 4
DIP-8_W7.62mm_Socket
Coilcraft-GA3460-BL
IDC-Header_2x05_P2.54mm_Horizontal
C_Rect_L31.5mm_W11.0mm_P27.50mm_MKS4
R_2512_6332Metric x 2
LED_0603_1608Metric
PinHeader_1x03_P2.54mm_Vertical
CP_Radial_D12.5mm_P5.00mm
Relay_StandexMeder_DIP_LowProfile
RaSens_copper
RaSens_silkscreen
RaSens_soldermask
RaSens_PCB

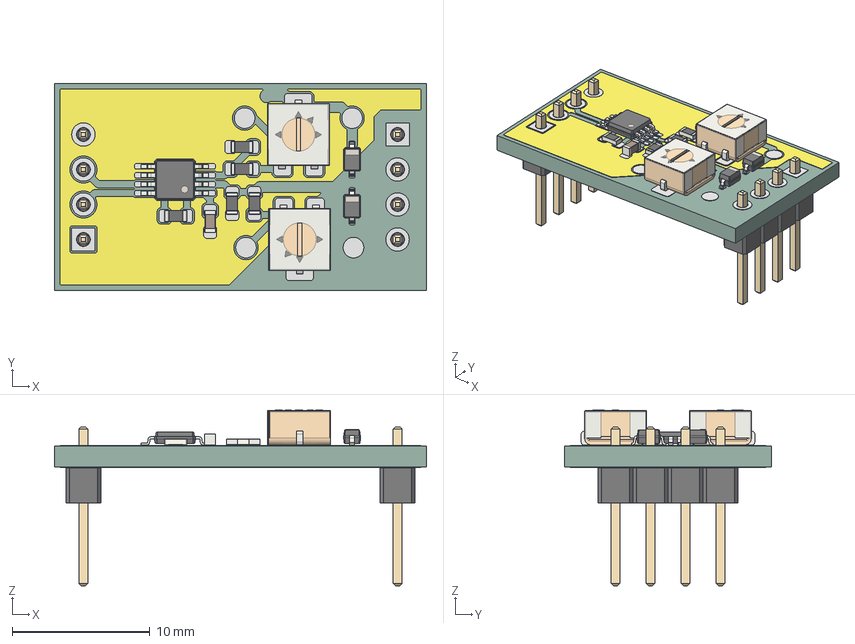
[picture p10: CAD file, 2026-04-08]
pcb/RaSensLite/Comparator.step
27.0 x 15.0 x 12.7 mm
MSOP-8_3x3mm_P0.65mm
R_0603_1608Metric x 5
D_SOD-323 x 2
C_0603_1608Metric
Potentiometer_Bourns_3314J_Vertical x 2
PinHeader_1x04_P2.54mm_Vertical x 2
Comparator_copper
Comparator_pad
Comparator_PCB

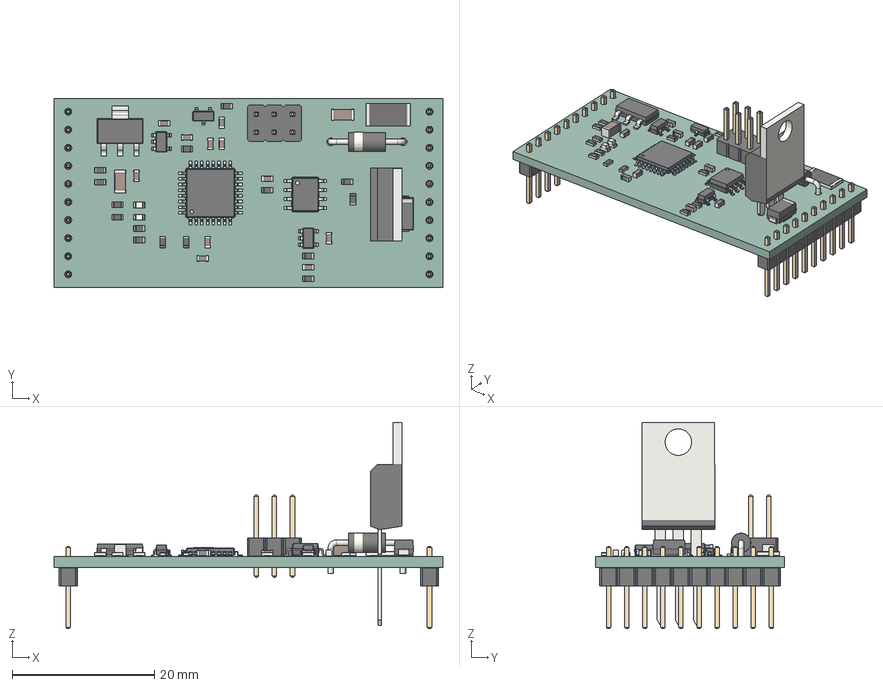
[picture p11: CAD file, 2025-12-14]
pcb/Switcher/Switcher.step
54.7 x 26.6 x 29.0 mm
R_0603_1608Metric x 15
D_SMA
C_0603_1608Metric x 9
SOT-23-5 x 2
TQFP-32_7x7mm_P0.8mm
C_1206_3216Metric x 2
SOT-223
L_0603_1608Metric x 2
D_DO-41_SOD81_P10.16mm_Horizontal
SOIC-8_3.9x4.9mm_P1.27mm
SOT-23
LED_0603_1608Metric x 2
R_2512_6332Metric
TO-220-3_Vertical
PinHeader_2x03_P2.54mm_Vertical
PinHeader_1x10_P2.54mm_Vertical x 2
Switcher_PCB

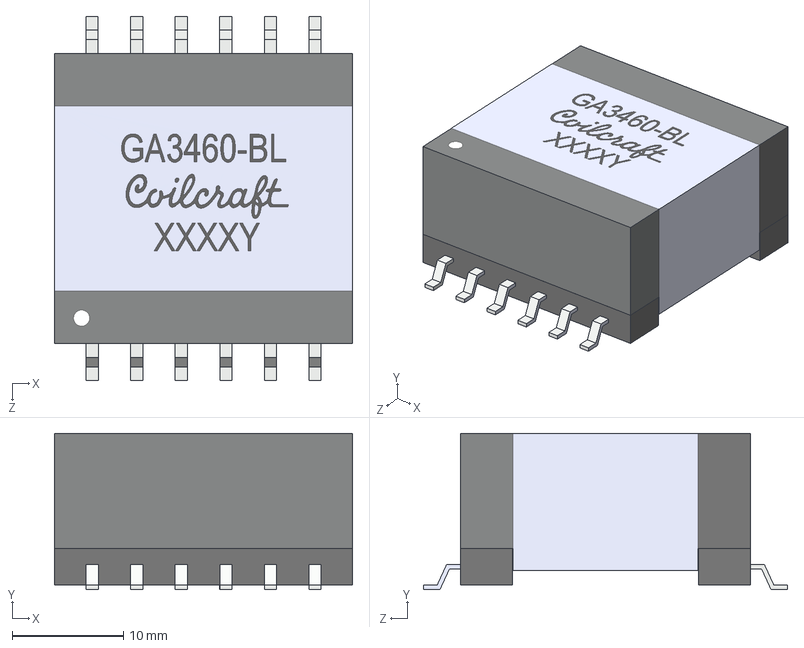
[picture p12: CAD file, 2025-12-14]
pcb/RaSens/3dshapes/Coilcraft-GA3460-BL.step
26.8 x 14.0 x 32.7 mm

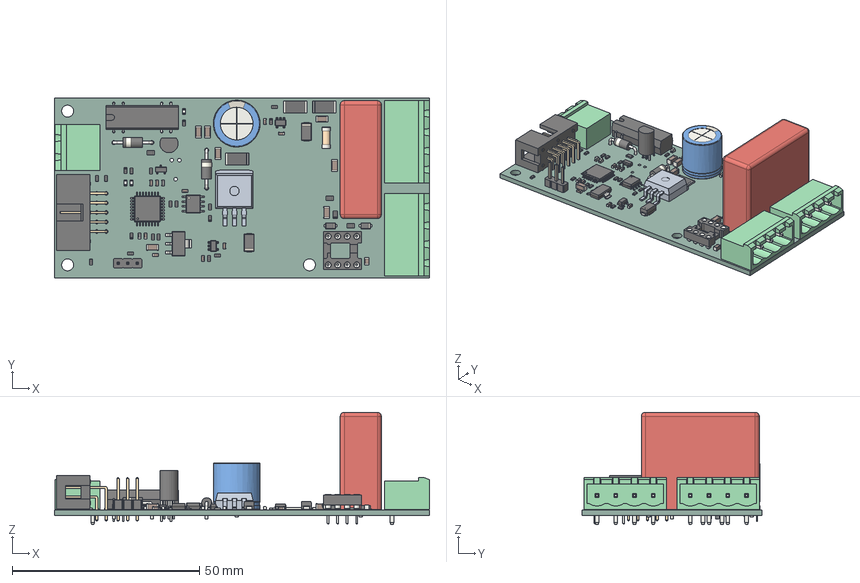
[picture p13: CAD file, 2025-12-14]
pcb/RaSensLite/RaSensLite.step
100.0 x 48.0 x 30.0 mm
R_0603_1608Metric x 19
PhoenixContact_MSTBA_2,5_4-G_1x04_P5.00mm_Horizontal x 2
C_1206_3216Metric x 7
D_DO-41_SOD81_P10.16mm_Horizontal x 2
C_0603_1608Metric x 9
L_0603_1608Metric x 2
SOT-223
C_0805_2012Metric
D_SMA x 2
R_MELF_MMB-0207
TQFP-32_7x7mm_P0.8mm
PhoenixContact_MSTBA_2,5_2-G-5,08_1x02_P5.08mm_Horizontal
LED_0603_1608Metric x 3
SOT-23-5 x 2
DIP-8_W7.62mm_Socket
R_0805_2012Metric x 4
PinHeader_1x03_P2.54mm_Vertical
C_Rect_L31.5mm_W11.0mm_P27.50mm_MKS4
SOIC-8_3.9x4.9mm_P1.27mm
R_2512_6332Metric x 3
RaSensLite 1.45.1
TO-92L_Inline
IDC-Header_2x05_P2.54mm_Horizontal
CP_Radial_D12.5mm_P5.00mm
Relay_StandexMeder_DIP_LowProfile
SOT-23
D_SOD-123F x 2
RaSensLite_PCB

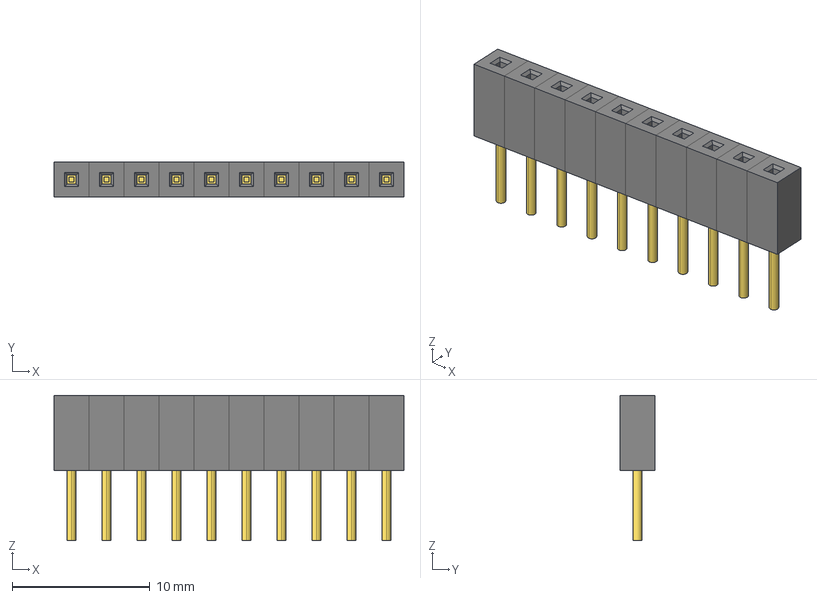
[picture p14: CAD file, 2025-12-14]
pcb/RaSens/3dshapes/5-535541-8_TYC.step
25.4 x 2.54 x 10.5 mm

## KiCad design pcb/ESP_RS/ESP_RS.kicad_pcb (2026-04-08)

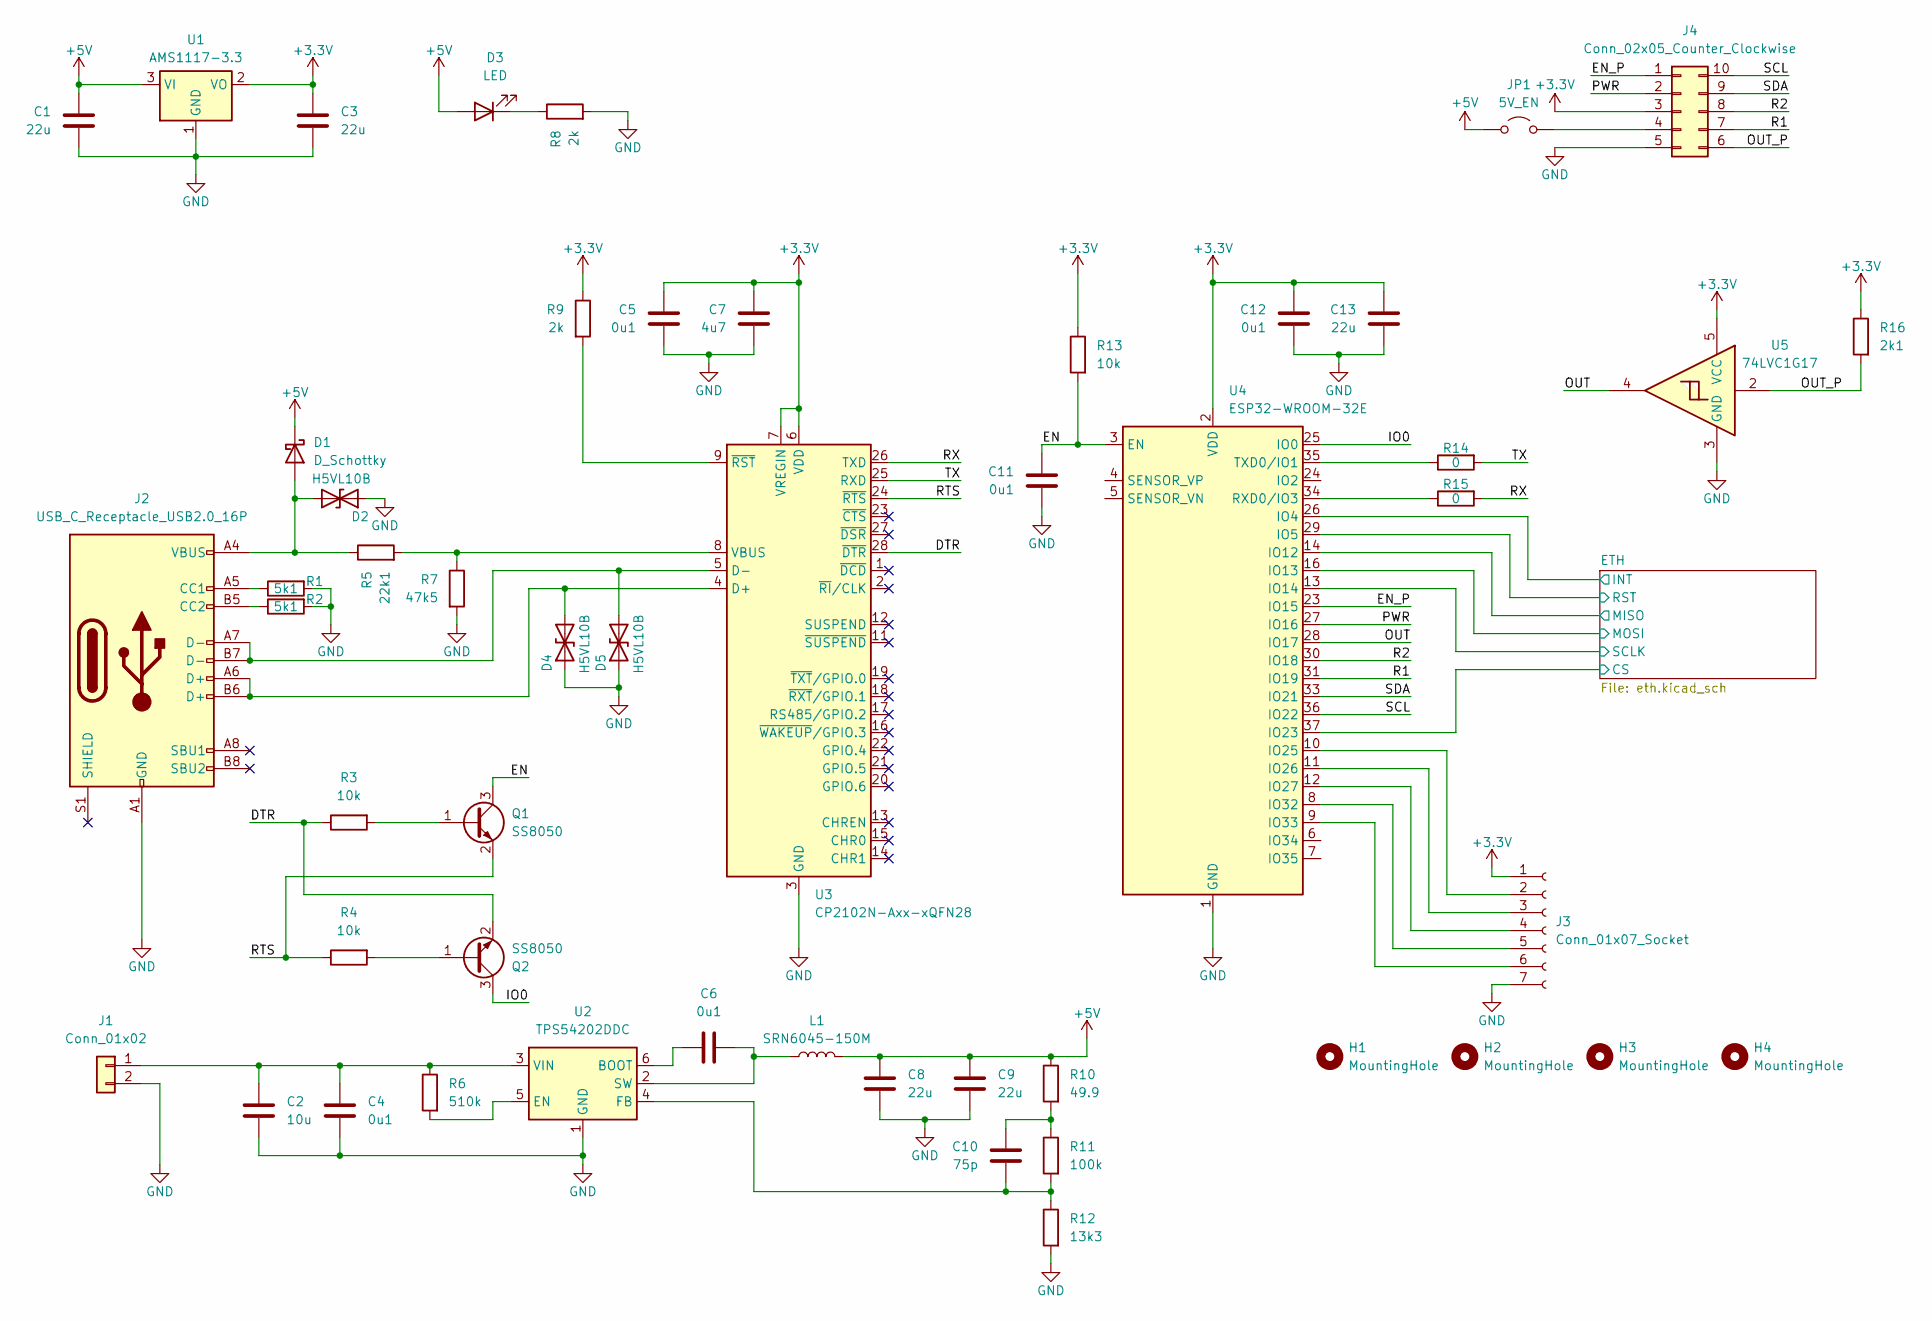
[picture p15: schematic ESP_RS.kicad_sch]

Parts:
C1, C3, C8, C9, C13: 22u; C_0603_1608Metric
C2: 10u; C_0805_2012Metric
C4, C6: 0u1; C_0805_2012Metric
C5, C11, C12: 0u1; C_0603_1608Metric
C7: 4u7; C_0603_1608Metric
C10: 75p; C_0603_1608Metric
D1: D_Schottky; D_SOD-323
D2, D4, D5: H5VL10B; D_SOD-882
D3: LED; LED_0603_1608Metric
H1, H2, H3, H4: MountingHole; MountingHole_3.2mm_M3_DIN965
J1: Conn_01x02; JST_XH_B2B-XH-AM_1x02_P2.50mm_Vertical
J2: USB_C_Receptacle_USB2.0_16P; USB_C_Receptacle_GCT_USB4105-xx-A_16P_TopMnt_Horizontal
J3: Conn_01x07_Socket; JST_XH_B7B-XH-A_1x07_P2.50mm_Vertical
J4: Conn_02x05_Counter_Clockwise; IDC-Header_2x05_P2.54mm_Horizontal
JP1: 5V_EN; TestPoint_2Pads_Pitch2.54mm_Drill0.8mm
L1: SRN6045-150M; L_Bourns_SRN6045TA
Q1, Q2: SS8050; SOT-23
R1, R2: 5k1; R_0603_1608Metric
R3, R4, R13: 10k; R_0603_1608Metric
R5: 22k1; R_0603_1608Metric
R6: 510k; R_0603_1608Metric
R7: 47k5; R_0603_1608Metric
R8, R9: 2k; R_0603_1608Metric
R10: 49.9; R_0603_1608Metric
R11: 100k; R_0603_1608Metric
R12: 13k3; R_0603_1608Metric
R14, R15: 0; R_0603_1608Metric
R16: 2k1; R_0603_1608Metric
U1: AMS1117-3.3; SOT-223-3_TabPin2
U2: TPS54202DDC; SOT-23-6
U3: CP2102N-Axx-xQFN28; QFN-28-1EP_5x5mm_P0.5mm_EP3.35x3.35mm
U4: ESP32-WROOM-32E; ESP32-WROOM-32D
U5: 74LVC1G17; SOT-23-5

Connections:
+3.3V: C3.1, C5.1, C7.1, C12.1, C13.1, J3.1, J4.3, R9.1, R13.1, R16.1, U1.2 (VO), U3.6 (VDD), U3.7 (VREGIN), U4.2 (VDD), U5.5 (VCC); also elsewhere on the board
+5V: C1.1, C8.1, C9.1, D1.1 (K), D3.2 (A), JP1.1 (A), L1.2, R10.1, U1.3 (VI)
/DTR: Q2.2 (E), R3.1, U3.28 (~DTR)
/EN: C11.1, Q1.3 (C), R13.2, U4.3 (EN)
/EN_P: J4.1, U4.23 (IO15)
/ETH/CS: U4.37 (IO23); also elsewhere on the board
/ETH/INT: U4.26 (IO4); also elsewhere on the board
/ETH/MISO: U4.14 (IO12); also elsewhere on the board
/ETH/MOSI: U4.16 (IO13); also elsewhere on the board
/ETH/RST: U4.29 (IO5); also elsewhere on the board
/ETH/SCLK: U4.13 (IO14); also elsewhere on the board
/IO0: Q2.3 (C), U4.25 (IO0)
/OUT: U4.28 (IO17), U5.4
/OUT_P: J4.6, R16.2, U5.2
/PWR: J4.2, U4.27 (IO16)
/R1: J4.7, U4.31 (IO19)
/R2: J4.8, U4.30 (IO18)
/RTS: Q1.2 (E), R4.1, U3.24 (~RTS)
/RX: R15.2, U3.26 (TXD)
/SCL: J4.10, U4.36 (IO22)
/SDA: J4.9, U4.33 (IO21)
/TX: R14.2, U3.25 (RXD)
GND: C1.2, C2.2, C3.2, C4.2, C5.2, C7.2, C8.2, C9.2, C11.2, C12.2, C13.2, D2.1 (A1), D4.1 (A1), D5.1 (A1), J1.2, J2.A1 (GND), J2.A12 (GND), J2.B1 (GND), J2.B12 (GND), J3.7, J4.5, R1.2, R2.2, R7.2, R8.2, R12.2, U1.1 (GND), U2.1 (GND), U3.3 (GND), U3.29 (GND), U4.1 (GND), U4.15 (GND), U4.38 (GND), U4.39 (GND), U5.3 (GND); also elsewhere on the board
unnamed: C10.1, R10.2, R11.1
unnamed: D1.2 (A), D2.2 (A2), J2.A4 (VBUS), J2.A9 (VBUS), J2.B4 (VBUS), J2.B9 (VBUS), R5.1
unnamed: D3.1 (K), R8.1
unnamed: D4.2 (A2), J2.A6 (D+), J2.B6 (D+), U3.4 (D+)
unnamed: D5.2 (A2), J2.A7 (D-), J2.B7 (D-), U3.5 (D-)
unnamed: C2.1, C4.1, J1.1, R6.1, U2.3 (VIN)
unnamed: J2.A5 (CC1), R1.1
unnamed: J2.B5 (CC2), R2.1
unnamed: J3.2, U4.10 (IO25)
unnamed: J3.3, U4.11 (IO26)
unnamed: J3.4, U4.12 (IO27)
unnamed: J3.5, U4.8 (IO32)
unnamed: J3.6, U4.9 (IO33)
unnamed: J4.4, JP1.2 (B)
unnamed: Q1.1 (B), R3.2
unnamed: Q2.1 (B), R4.2
unnamed: C6.1, U2.6 (BOOT)
unnamed: R6.2, U2.5 (EN)
unnamed: C10.2, R11.2, R12.1, U2.4 (FB)
unnamed: C6.2, L1.1, U2.2 (SW)
unnamed: R5.2, R7.1, U3.8 (VBUS)
unnamed: R9.2, U3.9 (~RST)
unnamed: R15.1, U4.34 (RXD0/IO3)
unnamed: R14.1, U4.35 (TXD0/IO1)

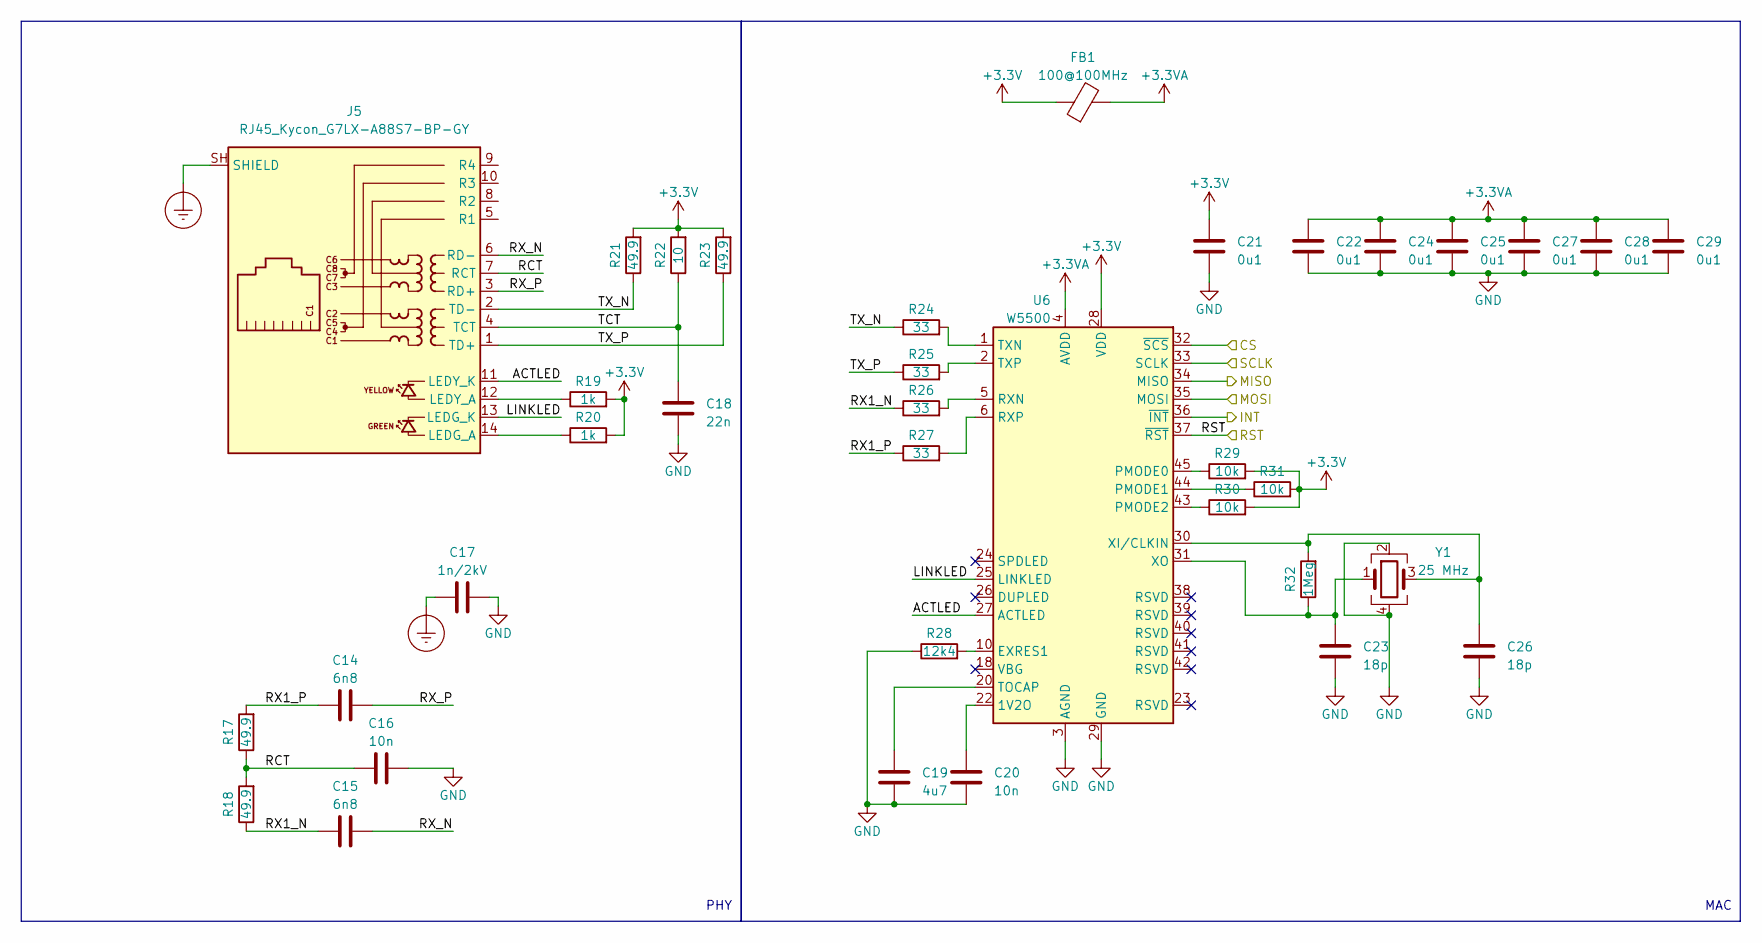
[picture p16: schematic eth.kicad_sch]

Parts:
C14, C15: 6n8; C_0603_1608Metric
C16, C20: 10n; C_0603_1608Metric
C17: 1n/2kV; C_1206_3216Metric
C18: 22n; C_0603_1608Metric
C19: 4u7; C_0603_1608Metric
C21, C22, C24, C25, C27, C28, C29: 0u1; C_0603_1608Metric
C23, C26: 18p; C_0603_1608Metric
FB1: 100@100MHz; L_0603_1608Metric
J5: RJ45_Kycon_G7LX-A88S7-BP-GY; RJ45_Kycon_G7LX-A88S7-BP-xx_Horizontal
R17, R18, R21, R23: 49.9; R_0402_1005Metric
R19, R20: 1k; R_0402_1005Metric
R22: 10; R_0402_1005Metric
R24, R25, R26, R27: 33; R_0402_1005Metric
R28: 12k4; R_0402_1005Metric
R29, R30, R31: 10k; R_0402_1005Metric
R32: 1Meg; R_0402_1005Metric
U6: W5500; LQFP-48_7x7mm_P0.5mm
Y1: 25 MHz; Crystal_SMD_Abracon_ABM8AIG-4Pin_3.2x2.5mm

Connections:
+3.3V: C21.1, FB1.1, R19.2, R20.2, R21.2, R22.2, R23.2, R29.2, R30.2, R31.2, U6.28 (VDD); also elsewhere on the board
+3.3VA: C22.1, C24.1, C25.1, C27.1, C28.1, C29.1, FB1.2, U6.4 (AVDD), U6.8 (AVDD), U6.11 (AVDD), U6.15 (AVDD), U6.17 (AVDD), U6.21 (AVDD)
/ETH/ACTLED: J5.11 (LEDY_K), U6.27 (ACTLED)
/ETH/CS: U6.32 (~SCS); also elsewhere on the board
/ETH/INT: U6.36 (~INT); also elsewhere on the board
/ETH/LINKLED: J5.13 (LEDG_K), U6.25 (LINKLED)
/ETH/MISO: U6.34 (MISO); also elsewhere on the board
/ETH/MOSI: U6.35 (MOSI); also elsewhere on the board
/ETH/RCT: C16.1, J5.7 (RCT), R17.1, R18.2
/ETH/RST: U6.37 (~RST); also elsewhere on the board
/ETH/RX1_N: C15.1, R18.1, R26.1
/ETH/RX1_P: C14.1, R17.2, R27.1
/ETH/RX_N: C15.2, J5.6 (RD-)
/ETH/RX_P: C14.2, J5.3 (RD+)
/ETH/SCLK: U6.33 (SCLK); also elsewhere on the board
/ETH/TCT: C18.1, J5.4 (TCT), R22.1
/ETH/TX_N: J5.2 (TD-), R21.1, R24.1
/ETH/TX_P: J5.1 (TD+), R23.1, R25.1
Earth_Protective: C17.1, J5.SH (SHIELD)
GND: C16.2, C17.2, C18.2, C19.2, C20.2, C21.2, C22.2, C23.2, C24.2, C25.2, C26.2, C27.2, C28.2, C29.2, R28.1, U6.3 (AGND), U6.9 (AGND), U6.14 (AGND), U6.16 (AGND), U6.19 (AGND), U6.29 (GND), U6.48 (AGND), Y1.2, Y1.4; also elsewhere on the board
unnamed: J5.14 (LEDG_A), R20.1
unnamed: J5.12 (LEDY_A), R19.1
unnamed: C20.1, U6.22 (1V2O)
unnamed: R28.2, U6.10 (EXRES1)
unnamed: R29.1, U6.45 (PMODE0)
unnamed: R31.1, U6.44 (PMODE1)
unnamed: R30.1, U6.43 (PMODE2)
unnamed: R26.2, U6.5 (RXN)
unnamed: R27.2, U6.6 (RXP)
unnamed: C19.1, U6.20 (TOCAP)
unnamed: R24.2, U6.1 (TXN)
unnamed: R25.2, U6.2 (TXP)
unnamed: C26.1, R32.2, U6.30 (XI/CLKIN), Y1.3
unnamed: C23.1, R32.1, U6.31 (XO), Y1.1

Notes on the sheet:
MAC
PHY

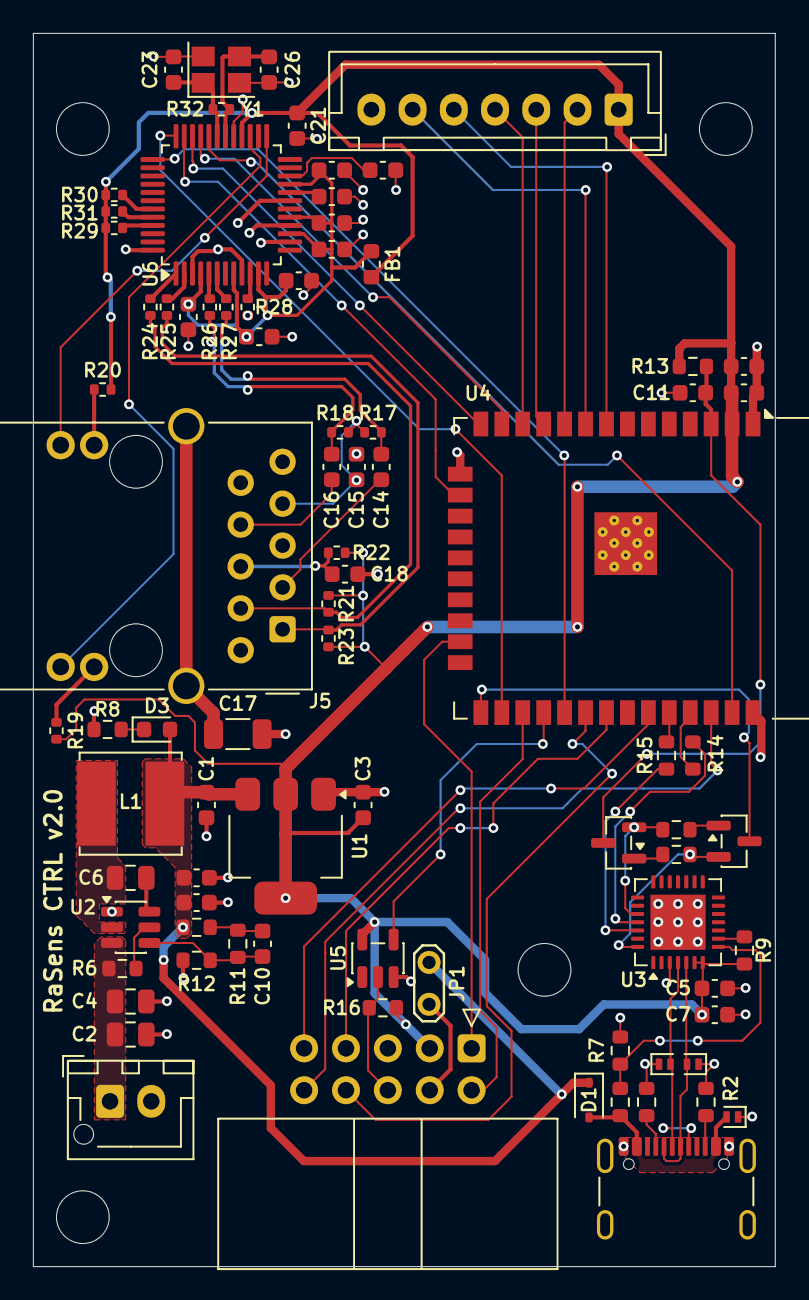
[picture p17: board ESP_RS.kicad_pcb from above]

Board: 2 copper layers, 45.0 x 74.8 mm, 87 parts (0 on the bottom side), 73 nets.

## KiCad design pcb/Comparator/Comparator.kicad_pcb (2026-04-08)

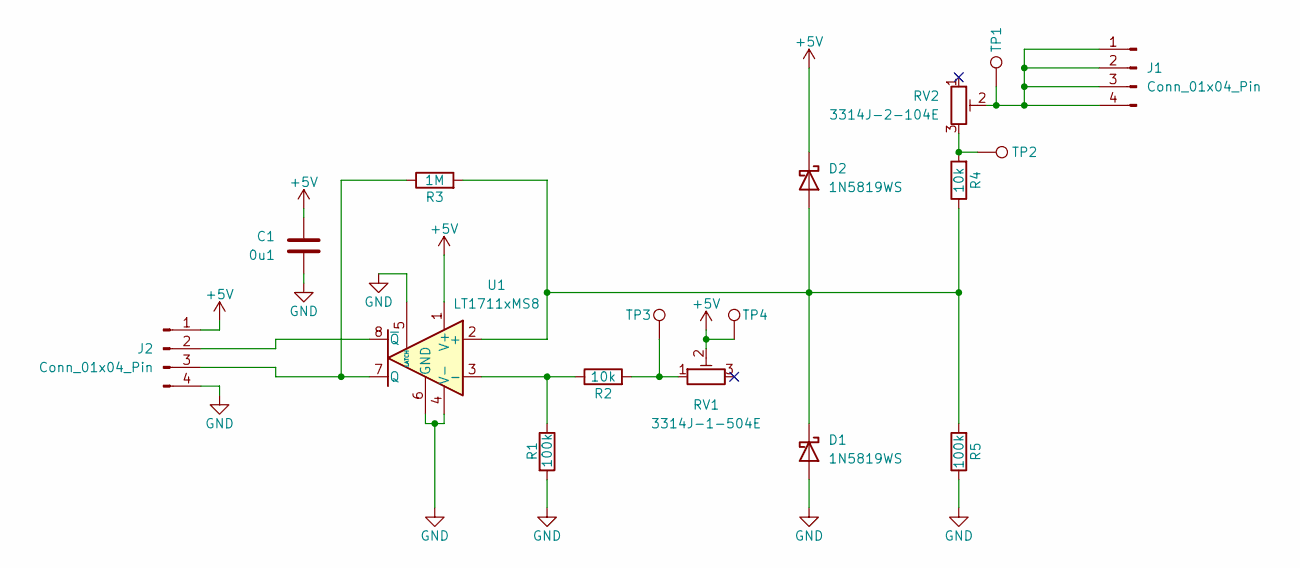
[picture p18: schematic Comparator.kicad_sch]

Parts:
C1: 0u1; C_0603_1608Metric
D1, D2: 1N5819WS; D_SOD-323
J1, J2: Conn_01x04_Pin; PinHeader_1x04_P2.54mm_Vertical
R1, R5: 100k; R_0603_1608Metric
R2, R4: 10k; R_0603_1608Metric
R3: 1M; R_0603_1608Metric
RV1: 3314J-1-504E; Potentiometer_Bourns_3314J_Vertical
RV2: 3314J-2-104E; Potentiometer_Bourns_3314J_Vertical
TP1, TP2, TP3, TP4: TestPoint; TestPoint_Pad_D1.5mm
U1: LT1711xMS8; MSOP-8_3x3mm_P0.65mm

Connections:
+5V: C1.1, D2.1 (K), J2.1, RV1.2, TP4.1, U1.1 (V+)
GND: C1.2, D1.2 (A), J2.4, R1.2, R5.1, U1.4 (V-), U1.5 (LATCH), U1.6 (GND)
unnamed: D1.1 (K), D2.2 (A), R3.2, R4.1, R5.2, U1.2 (+)
unnamed: J1.1, J1.2, J1.3, J1.4, RV2.2, TP1.1
unnamed: J2.2, U1.8 (~Q)
unnamed: J2.3, R3.1, U1.7 (Q)
unnamed: R2.2, RV1.1, TP3.1
unnamed: R4.2, RV2.3, TP2.1
unnamed: R1.1, R2.1, U1.3 (-)

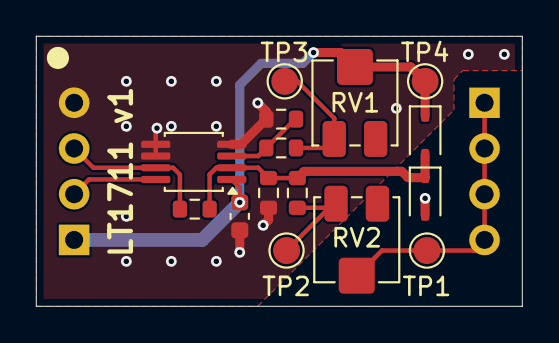
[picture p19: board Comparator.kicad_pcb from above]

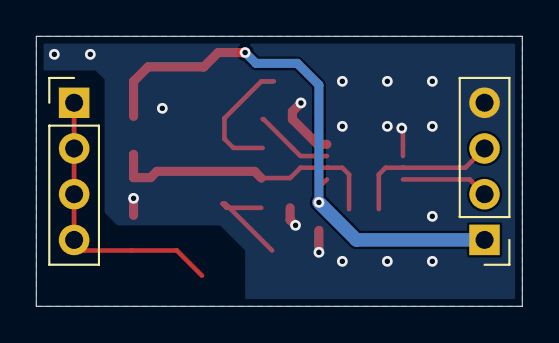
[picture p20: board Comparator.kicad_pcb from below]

Board: 2 copper layers, 27.0 x 15.0 mm, 17 parts (2 on the bottom side), 9 nets.

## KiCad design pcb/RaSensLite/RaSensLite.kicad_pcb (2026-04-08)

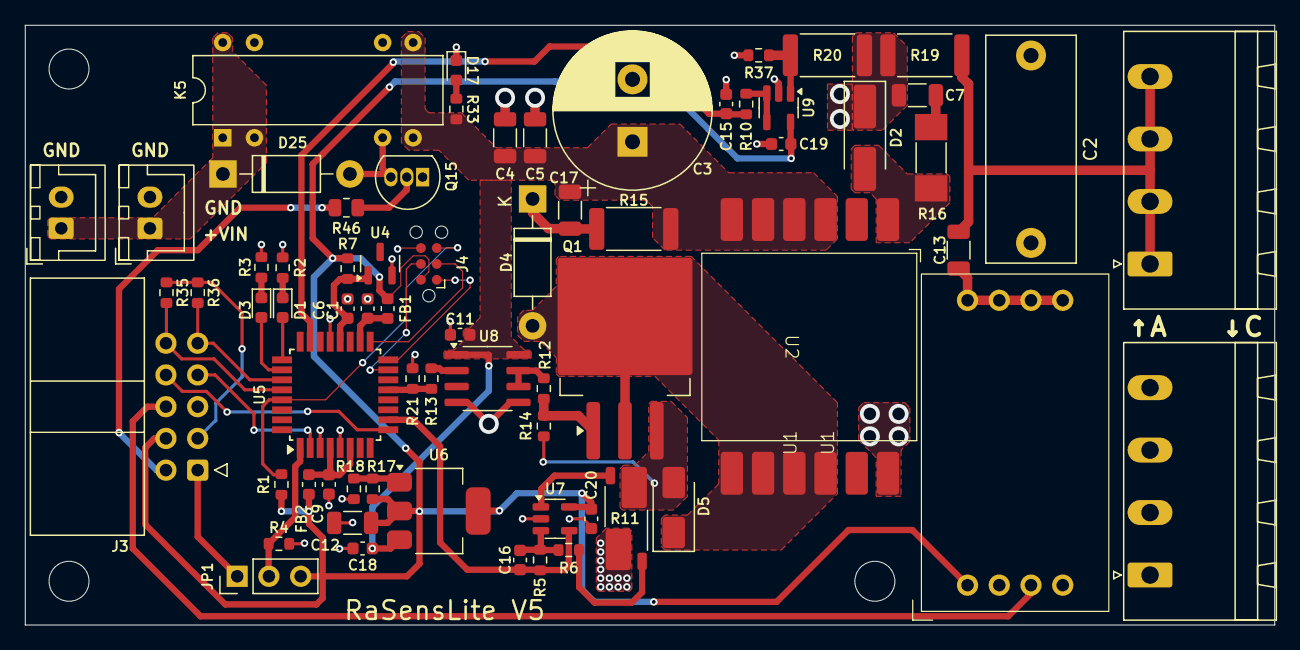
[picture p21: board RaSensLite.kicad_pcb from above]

Board: 2 copper layers, 100.0 x 48.0 mm, 71 parts (0 on the bottom side), 47 nets.

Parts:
C1, C6, C9, C18, C19, C20: 100n; C_0603_1608Metric
C2: ECW-FD2J105PQ; C_Rect_L18.0mm_W7.0mm_P15.00mm_FKS3_FKP3
C3: EEU-FM1V102; CP_Radial_D12.5mm_P5.00mm
C4, C5: 2u2; C_1206_3216Metric
C7: 100p; C_1206_3216Metric
C11: 1u; C_0603_1608Metric
C12: 10u; C_1206_3216Metric
C13: 10p; C_1206_3216Metric
C15: 22n; C_0603_1608Metric
C16: 220p; C_0603_1608Metric
C17: 1n; C_1206_3216Metric
D1: STATUS1; LED_0603_1608Metric
D2: VS-E7MH0112; D_SMA_Handsoldering
D3: STATUS2; LED_0603_1608Metric
D4, D25: UF4007; D_DO-41_SOD81_P10.16mm_Horizontal
D5: SMAJ150A; D_SMA
D17: LED; LED_0603_1608Metric
FB1, FB2: BLM18AG601SN1; L_0603_1608Metric
H1, H2, H4: MountingHole; MountingHole_3.2mm_M3_ISO7380
J1, J2: TBP04R12-500-04BE; PhoenixContact_MSTBA_2,5_4-G_1x04_P5.00mm_Horizontal
J3: Conn_02x05_Counter_Clockwise; IDC-Header_2x05_P2.54mm_Horizontal
J4: TC2030; Tag-Connect_TC2030-IDC-NL_2x03_P1.27mm_Vertical
J5, J6: Conn_01x02; JST_XH_B2B-XH-A_1x02_P2.50mm_Vertical
JP1: Jumper_3_Open; PinHeader_1x03_P2.54mm_Vertical
K5: DIP12-1A72-11L; Relay_StandexMeder_DIP_LowProfile
Q1: IPP075N15N3; TO-263-3_TabPin2
Q15: 2N2222A; TO-92L_Inline
R1, R4, R6, R7, R35, R36, R37: 10k; R_0603_1608Metric
R2, R3, R10, R13: 1k; R_0603_1608Metric
R5: 91k; R_0603_1608Metric
R11: 140m; R_Shunt_Vishay_WSK2512_6332Metric_T2.21mm
R12: 10; R_0603_1608Metric
R14, R21: 47k; R_0603_1608Metric
R15: 330; R_2512_6332Metric
R16: MMP100FRF100R; R_MELF_MMB-0207
R17: 240; R_0603_1608Metric
R18: 720; R_0603_1608Metric
R19: HV733ATTE2004F; R_2512_6332Metric
R20: HV733ATTE4304F; R_2512_6332Metric
R33: 4k7; R_0603_1608Metric
R46: 1k; R_0805_2012Metric
U1: COMPARATOR
U2: DA2032-AL
U4: LM4040DBZ-2.5; SOT-23
U5: ATmega328P-A; TQFP-32_7x7mm_P0.8mm
U6: LM317_SOT-223; SOT-223-3_TabPin2
U7, U9: LM321; SOT-23-5
U8: TC4420; SOIC-8_3.9x4.9mm_P1.27mm

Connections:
+3.3V: J3.3, R35.2, R36.2
+5V: C12.2, C19.2, C20.2, FB1.1, FB2.1, J3.4, J4.2, JP1.3 (B), R1.1, R7.1, R17.1, U1.1 (+5V), U6.2 (VO), U7.5 (V+), U9.5 (V+)
/GEIGER_OUTPUT: J3.6, U1.3 (OUT)
/PSU_EN: JP1.2 (C), R4.1, U5.1 (PD3)
/PSU_EN1: J3.1, JP1.1 (A)
/PWR_EN: J3.2, R46.2
/R1: J3.7, U5.2 (PD4)
/R2: J3.8, U5.9 (PD5)
/SCL: J3.10, R35.1, U5.28 (PC5)
/SDA: J3.9, R36.1, U5.27 (PC4)
/VIN: C3.1, C4.1, C5.1, C11.1, C17.2, C18.2, K5.7, K5.8, R15.1, R33.2, U2.3, U2.4, U2.5, U2.6, U6.3 (VI), U8.1 (VDD), U8.8 (VDD)
/switcher/AD0: C15.2, R10.1, U5.23 (PC0)
/switcher/AIN1: C16.1, R5.1, U5.10 (PD6), U7.4
/switcher/FB: R20.1, R37.2, U9.1 (+)
/switcher/GATE: R12.1, U8.6 (OUTPUT), U8.7 (OUTPUT)
/switcher/MISO: J4.1, U5.16 (PB4)
/switcher/MOSI: J4.4, U5.15 (PB3)
/switcher/PWM: R13.1, R21.2, U5.13 (PB1)
/switcher/RST: J4.5, R1.2, U5.29 (~RESET/PC6)
/switcher/SCK: J4.3, U5.17 (PB5)
/switcher/SHUNT_N: R6.1, R11.3
/switcher/SHUNT_P: R11.2, U7.1 (+)
/switcher/STATUS0: D1.2 (A), U5.25 (PC2)
/switcher/STATUS1: D3.2 (A), U5.26 (PC3)
/switcher/T-: D4.2 (A), D5.1 (A1), Q1.2 (D), U2.7, U2.8, U2.9, U2.10
GND: C1.2, C2.2, C3.2, C4.2, C5.2, C6.2, C9.2, C11.2, C12.1, C15.1, C18.1, C19.1, C20.1, D17.1 (K), J2.1, J2.2, J2.3, J2.4, J3.5, J4.6, J5.2, J6.2, Q15.1 (E), R2.2, R3.2, R4.2, R11.4, R18.2, R21.1, R37.1, U1.4 (GND), U2.12, U4.2 (A), U5.3 (GND), U5.5 (GND), U5.21 (GND), U7.2 (V-), U8.4 (GND), U8.5 (GND), U9.2 (V-)
unnamed: C7.1, R16.2
unnamed: C9.1, FB2.2, U5.4 (VCC), U5.6 (VCC)
unnamed: C13.2, U1.5 (IN), U1.6 (IN), U1.7 (IN), U1.8 (IN)
unnamed: D1.1 (K), R2.1
unnamed: D2.2 (A), R16.1, U2.1
unnamed: C2.1, C7.2, D2.1 (K), R19.1, R20.2
unnamed: D3.1 (K), R3.1
unnamed: C17.1, D4.1 (K), R15.2
unnamed: D5.2 (A2), Q1.3 (S), R11.1, R14.1
unnamed: D17.2 (A), R33.1
unnamed: D25.2 (A), K5.6, Q15.3 (C)
unnamed: D25.1 (K), J5.1, J6.1, K5.1, K5.2, K5.14
unnamed: C13.1, J1.1, J1.2, J1.3, J1.4, R19.2
unnamed: Q1.1 (G), R12.2, R14.2
unnamed: Q15.2 (B), R46.1
unnamed: C6.1, R7.2, U4.1 (K), U5.20 (AREF)
unnamed: C1.1, FB1.2, U5.18 (AVCC)
unnamed: R17.2, R18.1, U6.1 (ADJ)
unnamed: C16.2, R5.2, R6.2, U7.3 (-)
unnamed: R13.2, U8.2 (INPUT)
unnamed: R10.2, U9.3 (-), U9.4

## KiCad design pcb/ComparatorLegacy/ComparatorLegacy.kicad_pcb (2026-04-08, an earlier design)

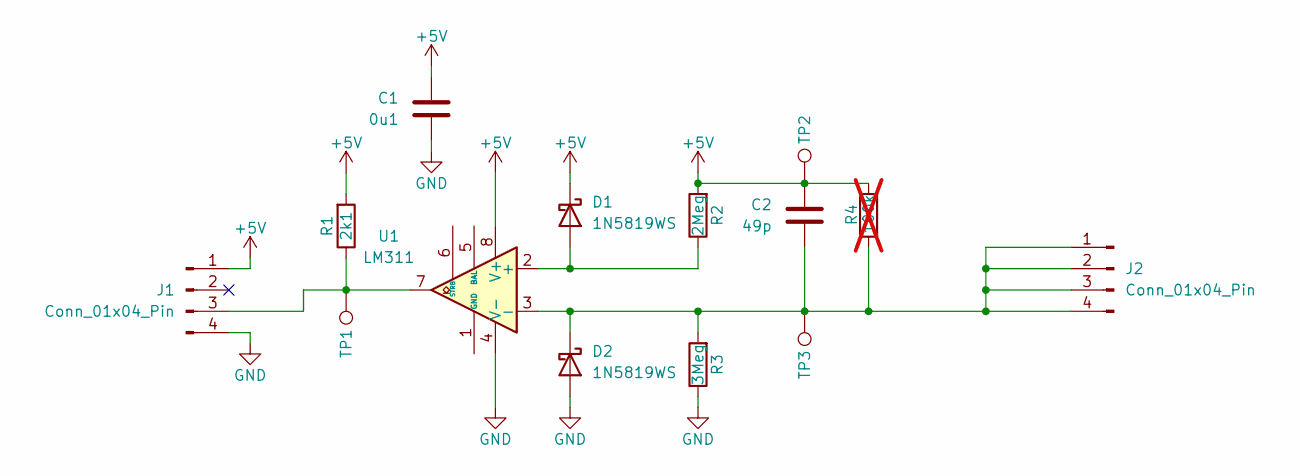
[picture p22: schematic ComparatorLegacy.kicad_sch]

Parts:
C1: 0u1; C_0603_1608Metric
C2: 49p; C_0603_1608Metric
D1, D2: 1N5819WS; D_SOD-323
J1, J2: Conn_01x04_Pin; PinHeader_1x04_P2.54mm_Vertical
R1: 2k1; R_0603_1608Metric
R2: 2Meg; R_0603_1608Metric
R3: 3Meg; R_0603_1608Metric
R4: 100k; R_0603_1608Metric; not fitted
TP1, TP2, TP3: TestPoint; TestPoint_Pad_D1.5mm
U1: LM311; DIP-8_W7.62mm

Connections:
+5V: C1.1, C2.1, D1.1 (K), J1.1, R1.2, R2.2, R4.1, TP2.1, U1.8 (V+)
GND: C1.2, D2.2 (A), J1.4, R3.1, U1.4 (V-)
unnamed: D1.2 (A), R2.1, U1.2 (+)
unnamed: C2.2, D2.1 (K), J2.1, J2.2, J2.3, J2.4, R3.2, R4.2, TP3.1, U1.3 (-)
unnamed: J1.3, R1.1, TP1.1, U1.7

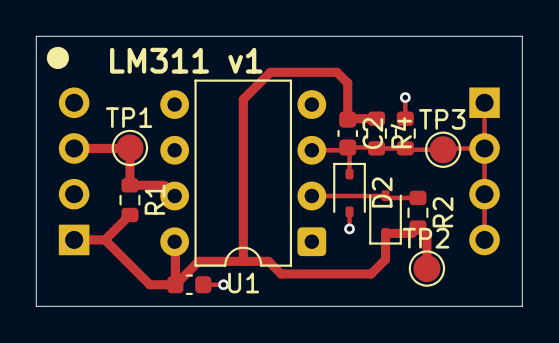
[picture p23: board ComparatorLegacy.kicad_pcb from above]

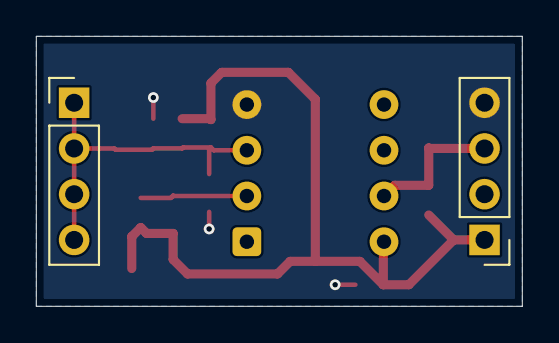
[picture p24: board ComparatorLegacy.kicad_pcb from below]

Board: 2 copper layers, 27.0 x 15.0 mm, 14 parts (2 on the bottom side), 5 nets.

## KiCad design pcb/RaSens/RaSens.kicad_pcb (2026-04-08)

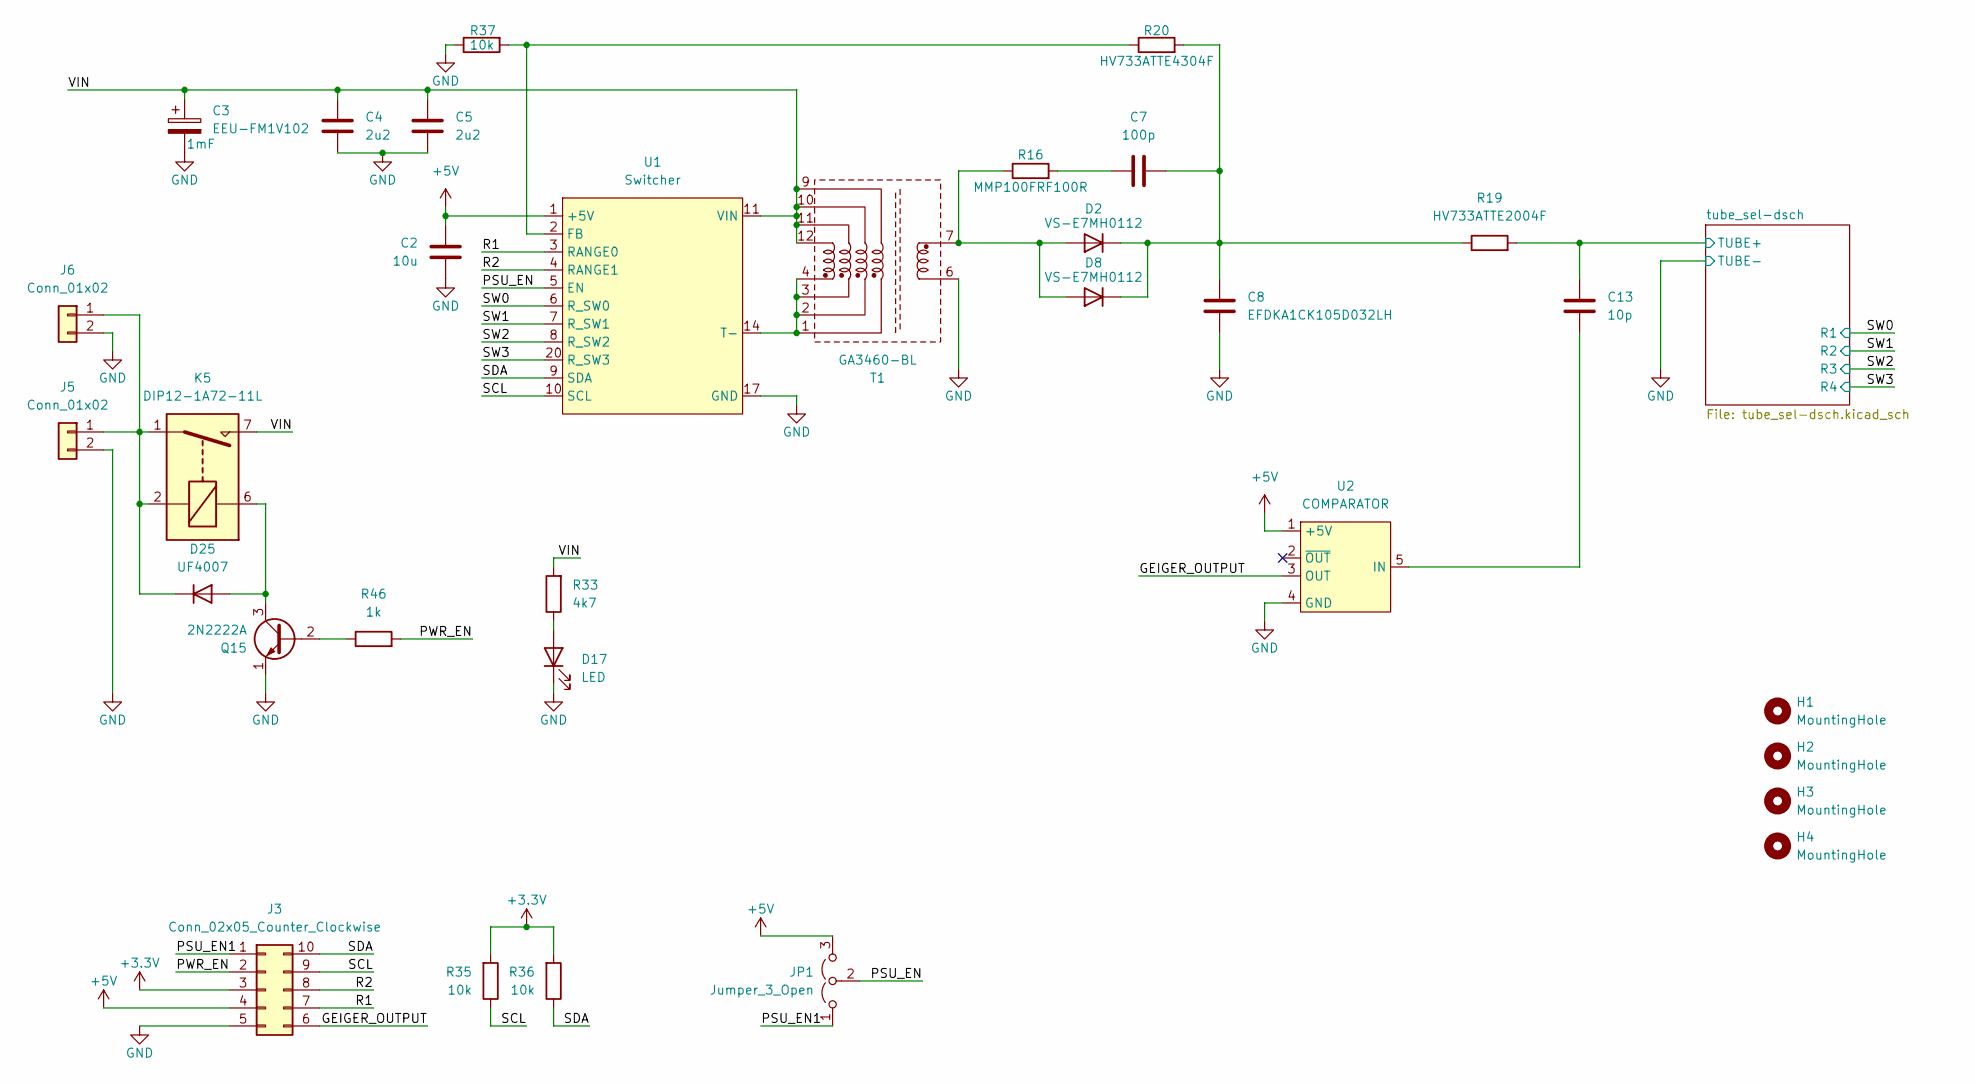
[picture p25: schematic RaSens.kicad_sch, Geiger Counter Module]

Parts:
C2: 10u; C_1206_3216Metric
C3: EEU-FM1V102; CP_Radial_D12.5mm_P5.00mm
C4, C5: 2u2; C_1206_3216Metric
C7: 100p; C_1206_3216Metric
C8: EFDKA1CK105D032LH; C_Rect_L31.5mm_W11.0mm_P27.50mm_MKS4
C13: 10p; C_1206_3216Metric
D2, D8: VS-E7MH0112; D_SMA-SMB_Universal_Handsoldering
D17: LED; LED_0603_1608Metric
D25: UF4007; D_DO-41_SOD81_P10.16mm_Horizontal
H1, H2, H3, H4: MountingHole; MountingHole_3.2mm_M3_ISO7380
J3: Conn_02x05_Counter_Clockwise; IDC-Header_2x05_P2.54mm_Horizontal
J5, J6: Conn_01x02; JST_XH_B2B-XH-A_1x02_P2.50mm_Vertical
JP1: Jumper_3_Open; PinHeader_1x03_P2.54mm_Vertical
K5: DIP12-1A72-11L; Relay_StandexMeder_DIP_LowProfile
Q15: 2N2222A; TO-92L_Inline
R16: MMP100FRF100R; R_MELF_MMB-0207
R19: HV733ATTE2004F; R_2512_6332Metric
R20: HV733ATTE4304F; R_2512_6332Metric
R33: 4k7; R_0603_1608Metric
R35, R36, R37: 10k; R_0603_1608Metric
R46: 1k; R_0805_2012Metric
T1: GA3460-BL; GA3460
U1: Switcher
U2: COMPARATOR

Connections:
+3.3V: J3.3, R35.2, R36.2
+5V: C2.1, J3.4, JP1.3 (B), U1.1 (+5V), U2.1 (+5V); also elsewhere on the board
/GEIGER_OUTPUT: J3.6, U2.3 (OUT)
/PSU_EN: JP1.2 (C), U1.5 (EN)
/PSU_EN1: J3.1, JP1.1 (A)
/PWR_EN: J3.2, R46.2
/R1: J3.7, U1.3 (RANGE0)
/R2: J3.8, U1.4 (RANGE1)
/SCL: J3.9, R35.1, U1.10 (SCL)
/SDA: J3.10, R36.1, U1.9 (SDA)
/SW0: U1.6 (R_SW0); also elsewhere on the board
/SW1: U1.7 (R_SW1); also elsewhere on the board
/SW2: U1.8 (R_SW2); also elsewhere on the board
/SW3: U1.20 (R_SW3); also elsewhere on the board
/VIN: C3.1, C4.1, C5.1, K5.7, K5.8, R33.2, T1.9, T1.10, T1.11, T1.12, U1.11 (VIN), U1.12 (VIN), U1.13 (VIN)
/tube_sel-dsch/TUBE+: C13.1, R19.2; also elsewhere on the board
GND: C2.2, C3.2, C4.2, C5.2, C8.2, D17.1 (K), J3.5, J5.2, J6.2, Q15.1 (E), R37.1, T1.6, U1.17 (GND), U1.18 (GND), U1.19 (GND), U2.4 (GND); also elsewhere on the board
unnamed: C7.1, R16.2
unnamed: C13.2, U2.5 (IN), U2.6 (IN), U2.7 (IN), U2.8 (IN)
unnamed: D2.2 (A), D8.2 (A), R16.1, T1.7
unnamed: C7.2, C8.1, D2.1 (K), D8.1 (K), R19.1, R20.2
unnamed: D17.2 (A), R33.1
unnamed: D25.2 (A), K5.6, Q15.3 (C)
unnamed: D25.1 (K), J5.1, J6.1, K5.1, K5.2, K5.14
unnamed: Q15.2 (B), R46.1
unnamed: T1.1, T1.2, T1.3, T1.4, U1.14 (T-), U1.15 (T-), U1.16 (T-)
unnamed: R20.1, R37.2, U1.2 (FB)

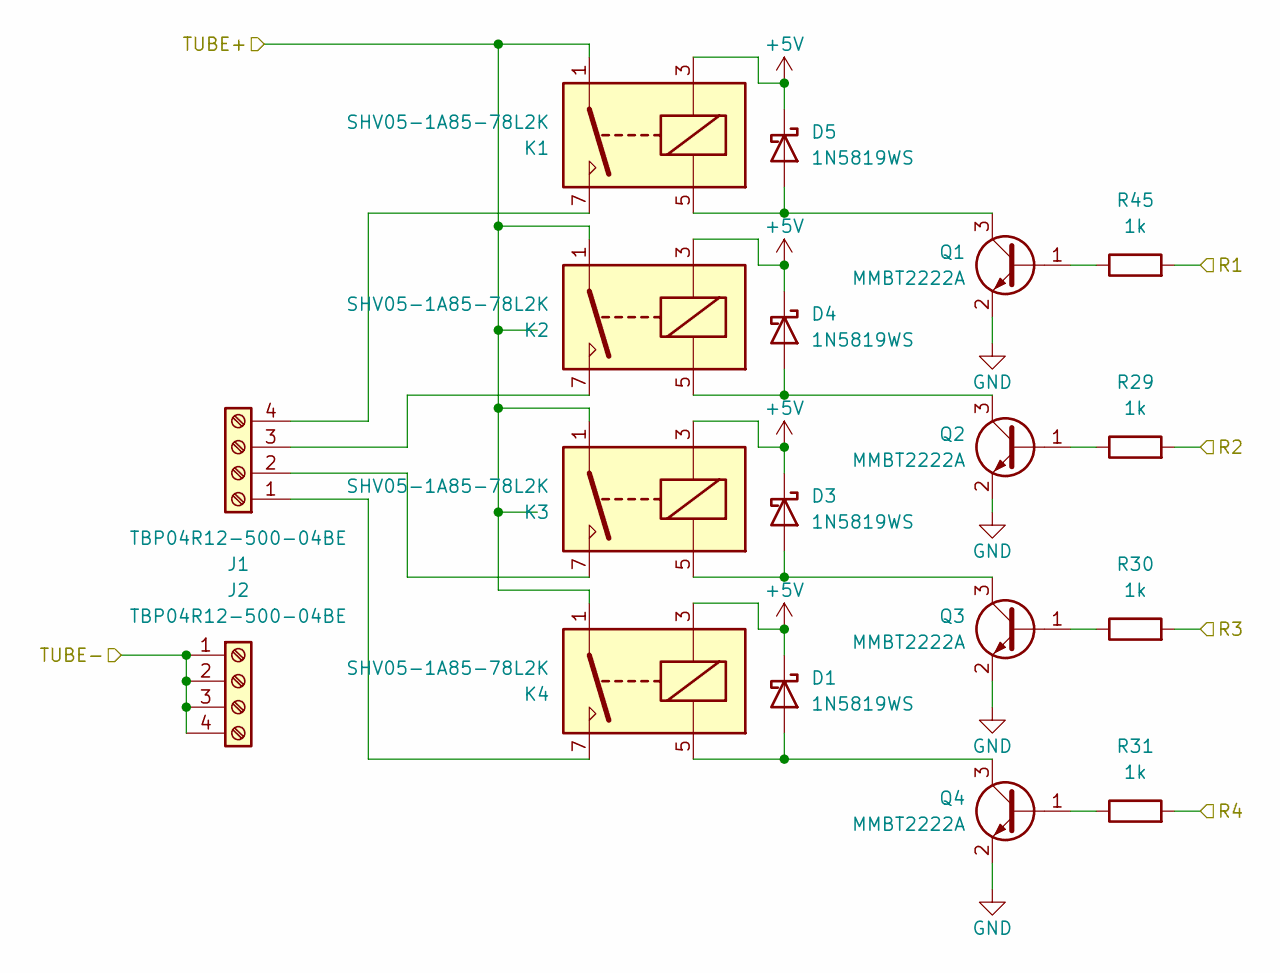
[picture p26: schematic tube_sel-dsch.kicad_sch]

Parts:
D1, D3, D4, D5: 1N5819WS; D_SOD-323
J1, J2: TBP04R12-500-04BE; PhoenixContact_MSTBA_2,5_4-G_1x04_P5.00mm_Horizontal
K1, K2, K3, K4: SHV05-1A85-78L2K; MEDER_SHV
Q1, Q2, Q3, Q4: MMBT2222A; SOT-23
R29, R30, R31, R45: 1k; R_0805_2012Metric

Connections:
+5V: D1.1 (K), D3.1 (K), D4.1 (K), D5.1 (K), K1.3, K2.3, K3.3, K4.3; also elsewhere on the board
/SW0: R45.2; also elsewhere on the board
/SW1: R29.2; also elsewhere on the board
/SW2: R30.2; also elsewhere on the board
/SW3: R31.2; also elsewhere on the board
/tube_sel-dsch/TUBE+: K1.1, K2.1, K3.1, K4.1; also elsewhere on the board
GND: J2.1, J2.2, J2.3, J2.4, Q1.2 (E), Q2.2 (E), Q3.2 (E), Q4.2 (E); also elsewhere on the board
unnamed: D1.2 (A), K4.5, Q4.3 (C)
unnamed: D3.2 (A), K3.5, Q3.3 (C)
unnamed: D4.2 (A), K2.5, Q2.3 (C)
unnamed: D5.2 (A), K1.5, Q1.3 (C)
unnamed: J1.1, K4.7
unnamed: J1.2, K3.7
unnamed: J1.3, K2.7
unnamed: J1.4, K1.7
unnamed: Q1.1 (B), R45.1
unnamed: Q2.1 (B), R29.1
unnamed: Q3.1 (B), R30.1
unnamed: Q4.1 (B), R31.1



Board: 2 copper layers, 167.0 x 48.0 mm, 50 parts (4 on the bottom side), 39 nets.

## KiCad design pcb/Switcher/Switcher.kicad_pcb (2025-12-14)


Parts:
J2, J3: Conn_01x10_Pin; PinHeader_1x10_P2.54mm_Vertical

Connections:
+5V: J3.1; also elsewhere on the board
/Core/EN: J3.5; also elsewhere on the board
/Core/FB: J3.2; also elsewhere on the board
/Core/RANGE0: J3.3; also elsewhere on the board
/Core/RANGE1: J3.4; also elsewhere on the board
/Core/R_SW0: J3.6; also elsewhere on the board
/Core/R_SW1: J3.7; also elsewhere on the board
/Core/R_SW2: J3.8; also elsewhere on the board
/Core/R_SW3: J2.10; also elsewhere on the board
/Core/SCL: J3.9; also elsewhere on the board
/Core/SDA: J3.10; also elsewhere on the board
/Core/T-: J2.4, J2.5, J2.6; also elsewhere on the board
/Core/VIN: J2.1, J2.2, J2.3; also elsewhere on the board
GND: J2.7, J2.8, J2.9; also elsewhere on the board

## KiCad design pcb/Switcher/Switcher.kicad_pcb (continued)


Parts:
C1, C2, C3, C4, C6, C8: 100n; C_0603_1608Metric
C5: 220p; C_0603_1608Metric
C7: 22n; C_0603_1608Metric
C9: 1n; C_1206_3216Metric
C10: 10u; C_1206_3216Metric
C11: 1u; C_0603_1608Metric
D1: LED_BLUE; LED_0603_1608Metric
D2: LED_RED; LED_0603_1608Metric
D3: UF4007; D_DO-41_SOD81_P10.16mm_Horizontal
D4: SMAJ150A; D_SMA
FB1, FB2: BLM18AG601SN1; L_0603_1608Metric
HS1: Heatsink; Heatsink_Stonecold_HS-S01_13.21x6.35mm
J1: TC2030; Tag-Connect_TC2030-IDC-NL_2x03_P1.27mm_Vertical
Q1: IPP075N15N3; TO-220-3_Vertical
R1, R4, R6, R7: 10k; R_0603_1608Metric
R2, R3, R10, R13: 1k; R_0603_1608Metric
R5: 91k; R_0603_1608Metric
R11: 140m; R_Shunt_Vishay_WSK2512_6332Metric_T2.21mm
R12: 10; R_0603_1608Metric
R14, R19: 47k; R_0603_1608Metric
R15: 330; R_2512_6332Metric
R16: 240; R_0603_1608Metric
R17: 720; R_0603_1608Metric
U1: ATmega328P-A; TQFP-32_7x7mm_P0.8mm
U2, U4: LM321; SOT-23-5
U3: LM4040DBZ-2.5; SOT-23
U5: TC4420; SOIC-8_3.9x4.9mm_P1.27mm
U6: LM317_SOT-223; SOT-223-3_TabPin2

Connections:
+5V: C4.2, C6.2, C10.2, FB1.1, FB2.1, J1.2, R1.1, R7.1, R16.1, U2.5 (V+), U4.5 (V+), U6.2 (VO); also elsewhere on the board
/Core/AD0: C7.2, R10.1, U1.23 (PC0)
/Core/AD1: U1.24 (PC1)
/Core/AIN0: U1.11 (PD7)
/Core/AIN1: C5.1, R5.1, U1.10 (PD6), U2.4
/Core/EN: R4.1, U1.1 (PD3); also elsewhere on the board
/Core/FB: U4.1 (+); also elsewhere on the board
/Core/GATE: R12.1, U5.6 (OUTPUT), U5.7 (OUTPUT)
/Core/MISO: J1.1, U1.16 (PB4)
/Core/MOSI: J1.4, U1.15 (PB3)
/Core/PWM: R13.1, R19.2, U1.13 (PB1)
/Core/RANGE0: U1.2 (PD4); also elsewhere on the board
/Core/RANGE1: U1.9 (PD5); also elsewhere on the board
/Core/RST: J1.5, R1.2, U1.29 (~RESET/PC6)
/Core/R_SW0: U1.7 (XTAL1/PB6); also elsewhere on the board
/Core/R_SW1: U1.8 (XTAL2/PB7); also elsewhere on the board
/Core/R_SW2: U1.30 (PD0); also elsewhere on the board
/Core/R_SW3: U1.31 (PD1); also elsewhere on the board
/Core/SCK: J1.3, U1.17 (PB5)
/Core/SCL: U1.28 (PC5); also elsewhere on the board
/Core/SDA: U1.27 (PC4); also elsewhere on the board
/Core/SHUNT_N: R6.1, R11.3
/Core/SHUNT_P: R11.2, U2.1 (+)
/Core/STATUS0: D1.2 (A), U1.25 (PC2)
/Core/STATUS1: D2.2 (A), U1.26 (PC3)
/Core/T-: D3.2 (A), D4.1 (A1), Q1.2 (D); also elsewhere on the board
/Core/VIN: C8.2, C9.2, C11.1, R15.1, U5.1 (VDD), U5.8 (VDD), U6.3 (VI); also elsewhere on the board
GND: C1.2, C2.2, C3.2, C4.1, C6.1, C7.1, C8.1, C10.1, C11.2, J1.6, R2.2, R3.2, R4.2, R11.4, R17.2, R19.1, U1.3 (GND), U1.5 (GND), U1.21 (GND), U2.2 (V-), U3.2 (A), U4.2 (V-), U5.4 (GND), U5.5 (GND); also elsewhere on the board
unnamed: C2.1, FB2.2, U1.4 (VCC), U1.6 (VCC)
unnamed: D1.1 (K), R2.1
unnamed: D2.1 (K), R3.1
unnamed: C9.1, D3.1 (K), R15.2
unnamed: D4.2 (A2), Q1.3 (S), R11.1, R14.1
unnamed: Q1.1 (G), R12.2, R14.2
unnamed: C3.1, R7.2, U1.20 (AREF), U3.1 (K)
unnamed: C1.1, FB1.2, U1.18 (AVCC)
unnamed: C5.2, R5.2, R6.2, U2.3 (-)
unnamed: R10.2, U4.3 (-), U4.4
unnamed: R13.2, U5.2 (INPUT)
unnamed: R16.2, R17.1, U6.1 (ADJ)

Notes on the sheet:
OC AMP
FB AMP



Board: 2 copper layers, 54.7 x 26.6 mm, 44 parts (2 on the bottom side), 38 nets.

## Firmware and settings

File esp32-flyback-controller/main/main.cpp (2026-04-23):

#include <stdio.h>
#include "freertos/FreeRTOS.h"
#include "freertos/task.h"
#include "esp_log.h"
#include "flyback_psu.h"
#include "esp_timer.h"
#include "geiger_counter.h"
#include "driver/gpio.h"
#include "wifi.h"
#include "storage.h"
#include "iot_is.h"
#include "job_manager.h"
#include "ota.h"
#include "sntp.h"
#include "flyback.h"
#include "commands/commands.h"
#include "ble.h"
#include "provisioning.h"
#include "hv_mon.h"
#include "LAN.h"
#include "esp_mac.h"

static const char *TAG = "main";

geiger_counter_pcnt4_t gc;
device_config_data_t devCfg;

static void avg_u(void *p)
{
  const TickType_t period = pdMS_TO_TICKS(500); // 2 Hz sampling
  TickType_t last = xTaskGetTickCount();

  while (true)
  {
    vTaskDelayUntil(&last, period);

    flyback_psu_status_t s;
    if (flyback_get_status(&s) == ESP_OK)
    {
      float vfb = flyback_counts_to_volts(s.fb_counts);
      hv_avg_add(vfb);

      // optional: only log anomalies
      if (s.run_state != 0 || s.fault_code != 0)
      {
        ESP_LOGW(TAG, "PSU state=%u fault=%u V=%.1f busy=%u",
                 s.run_state, s.fault_code, vfb, s.range_busy);
      }
    }
    else
    {
      ESP_LOGW(TAG, "Failed to read PSU status");
    }
  }
}

extern "C" void app_main(void)
{
  gpio_config_t io_conf = {};
  io_conf.pin_bit_mask = ((1ULL << CONFIG_RASENS_ENABLE_PIN) | (1ULL << CONFIG_RASENS_SLEEP_PIN));
  io_conf.mode = GPIO_MODE_OUTPUT;
  io_conf.intr_type = GPIO_INTR_DISABLE;
  io_conf.pull_down_en = GPIO_PULLDOWN_ENABLE;
  io_conf.pull_up_en = GPIO_PULLUP_DISABLE;
  gpio_config(&io_conf);
  // disable flyback by default on boot for safety
  gpio_set_level((gpio_num_t)CONFIG_RASENS_SLEEP_PIN, 0);
  gpio_set_level((gpio_num_t)CONFIG_RASENS_ENABLE_PIN, 0);

  ESP_LOGI(TAG, "Boot...");
  // initialize storage
  storage_init();

  // mark app as valid to avoid rollback
  mark_app_valid_cancel_rollback();

  register_got_ip_callback(eth_connected_override);
  register_down_callback(eth_disconnected_override);

  ble_init();
  uint8_t mac[6];
  esp_read_mac(mac, ESP_MAC_BT);
  LAN_init();

  // initialize wifi
  wifi_init();

  provisioning_manager_init();

  // try to get provisioning data
  provisioning_data_t cfg = {0};
  bool have_nvs = (storage_load_provisioning_data(&cfg) == ESP_OK) && validate_prov(&cfg); // if validate_prov visible, copy same logic here
  if (!have_nvs)
  {
    memset(&cfg, 0, sizeof(cfg));
    strncpy(cfg.ssid, CONFIG_RASENS_DEFAULT_SSID, sizeof(cfg.ssid) - 1);
    strncpy(cfg.password, CONFIG_RASENS_DEFAULT_WIFI_PASSWORD, sizeof(cfg.password) - 1);
    strncpy(cfg.mqtt_host, CONFIG_RASENS_MQTT_HOST, sizeof(cfg.mqtt_host) - 1);
    cfg.mqtt_port = CONFIG_RASENS_MQTT_PORT;
    strncpy(cfg.access_token, CONFIG_RASENS_ACCESS_TOKEN, sizeof(cfg.access_token) - 1);
  }

  // Set supervisor active BEFORE starting supervisor task
  connection_supervisor_set_active(&cfg, have_nvs);

  // Start supervisor: it will retry indefinitely
  ESP_ERROR_CHECK(connection_supervisor_init());

  // try to load device configuration data

  if (storage_load_device_config_data(&devCfg) != ESP_OK)
  {
    ESP_LOGW(TAG, "No device configuration data found in storage, using defaults");
    devCfg.interval = 60; // 60 seconds
    devCfg.active_range = 0;
    devCfg.set_voltage[0] = 200; // R1
    devCfg.set_voltage[1] = 250; // R2
    devCfg.set_voltage[2] = 300; // R3
    devCfg.set_voltage[3] = 350; // R4
    devCfg.coeff[0] = 93;        // R1
    devCfg.coeff[1] = 62;        // R2
    devCfg.coeff[2] = 1111;      // R3
    devCfg.coeff[3] = 11111;     // R4

    // store defaults back to storage
    storage_save_device_config_data(&devCfg);
  }
  else
  {
    ESP_LOGI(TAG, "Loaded device configuration data: interval=%u s, active_range = %u", devCfg.interval, devCfg.active_range);
  }

  // wait for provisioning to complete
  ESP_LOGI(TAG, "Waiting for network (Wi-Fi or Ethernet)...");
  esp_err_t net_ready = wifi_wait_connected(pdMS_TO_TICKS(60000));

  if (net_ready == ESP_OK)
  {
    ESP_LOGI(TAG, "Network ready, starting online services");

    init_sntp(CONFIG_RASENS_SNTP_SYNC_INTERVAL_MS);

    updateFirmwareVersion(CONFIG_RASENS_HTTP_BACKEND_URL, cfg.access_token);
    perform_ota_update(CONFIG_RASENS_HTTP_BACKEND_URL, cfg.access_token);
  }
  else
  {
    ESP_LOGW(TAG, "No network within timeout, continuing in offline mode");
  }

  job_manager.init();
  job_manager.register_command("setTube", setTube_command);
  job_manager.register_command("setInterval", setIntervalCommand);
  job_manager.register_command("setVoltage_r1", setVoltage_r1_command);
  job_manager.register_command("setVoltage_r2", setVoltage_r2_command);
  job_manager.register_command("setVoltage_r3", setVoltage_r3_command);
  job_manager.register_command("setVoltage_r4", setVoltage_r4_command);
  job_manager.register_command("setConversion_r1", setConversion_r1_command);
  job_manager.register_command("setConversion_r2", setConversion_r2_command);
  job_manager.register_command("setConversion_r3", setConversion_r3_command);
  job_manager.register_command("setConversion_r4", setConversion_r4_command);
  job_manager.register_command("reset", resetCommand);
  job_manager.register_command("factoryReset", factoryResetCommand);


  // Initialize flyback PSU device context
  esp_err_t ret = ESP_FAIL;
  for (int i = 0; i < 3; i++)
  {
    ret = flyback_init();
    if (ret == ESP_OK)
    {
      break;
    }
    ESP_LOGE(TAG, "Flyback board failed to initialize: %s, trying again after 5s.", esp_err_to_name(ret));
    i2c_driver_delete(I2C_NUM_0);
    vTaskDelay(5000 / portTICK_PERIOD_MS);
  }

  if (ret != ESP_OK)
  {
    ESP_LOGE(TAG, "Flyback init failed permanently, restarting");
    abort();
  }

  flyback_set_voltage(0, static_cast<float>(devCfg.set_voltage[0]));
  flyback_set_voltage(1, static_cast<float>(devCfg.set_voltage[1]));
  flyback_set_voltage(2, static_cast<float>(devCfg.set_voltage[2]));
  flyback_set_voltage(3, static_cast<float>(devCfg.set_voltage[3]));

  // Optionally persist configuration to EEPROM (uncomment if desired)
  // ESP_ERROR_CHECK(flyback_psu_send_command(&psu, FLYBACK_CMD_SAVE_CONFIG));

  // accept pulses >= 1000 ns (1 µs),
  esp_err_t err = geiger_counter_pcnt_start(&gc, (gpio_num_t)CONFIG_RASENS_INTERRUPT_PIN, CONFIG_RASENS_INTERRUPT_PIN_ACTIVE_HIGH, 500);
  if (err != ESP_OK)
  {
    ESP_LOGE(TAG, "Failed to start counter: %s", esp_err_to_name(err));
  }

  geiger_counter_set_conversion_factor(&gc, 0, static_cast<float>(devCfg.coeff[0]) / 10000.0f); // R1
  geiger_counter_set_conversion_factor(&gc, 1, static_cast<float>(devCfg.coeff[1]) / 10000.0f); // R2
  geiger_counter_set_conversion_factor(&gc, 2, static_cast<float>(devCfg.coeff[2]) / 10000.0f); // R3
  geiger_counter_set_conversion_factor(&gc, 3, static_cast<float>(devCfg.coeff[3]) / 10000.0f); // R4

  // link Geiger counter device to flyback controller for range sync
  flyback_set_geiger_counter_device(&gc);

  // Enable flyback PSU output
  flyback_enable();

  // Wait for relay switching to complete (timeout 3 seconds)
  esp_err_t idle = flyback_wait_for_idle(3000, 10);
  if (idle != ESP_OK)
  {
    ESP_LOGW(TAG, "Timeout waiting for range switch to complete");
  }

  flyback_set_channel(devCfg.active_range);
  geiger_counter_set_active_range(&gc, devCfg.active_range);

  // Wait for relay switching to complete (timeout 3 seconds)
  idle = flyback_wait_for_idle(3000, 10);
  if (idle != ESP_OK)
  {
    ESP_LOGW(TAG, "Timeout waiting for range switch to complete");
  }

  hv_avg_init();
  xTaskCreate(avg_u, "average U", 4096, NULL, 6, NULL);

  while (true)
  {
    // wait 1 minute before next measurement
    vTaskDelay(pdMS_TO_TICKS((uint32_t)devCfg.interval * 1000UL));
    /*flyback_wake();
    flyback_enable();
    geiger_counter_pcnt_resume(&gc);*/

    // Measure for 1 minute */
    // vTaskDelay(pdMS_TO_TICKS(60000));
    // Read Geiger counter statistics
    float cpm = geiger_counter_pcnt_get_cpm(&gc, devCfg.active_range);
    float usvh = geiger_counter_pcnt_get_sieverts_per_hour(&gc, devCfg.active_range);
    uint64_t total = geiger_counter_pcnt_get_total(&gc, devCfg.active_range);
    float cr = 0;
    float dr = 0;
    geiger_counter_pcnt_get_cr_dr(&gc, devCfg.active_range, &cr, &dr);
    ESP_LOGI("GEIGER", "Counts: CPM=%.1f uSv/h=%.3f Total=%llu", cpm, usvh, (unsigned long long)total);

    // get current ts
    time_t now;
    time(&now);
    // iotIs.send_data("cps", cps, now);
    
    uint8_t curCh = 0;
    flyback_get_channel(&curCh);
    int iface = 0;
    if (eth_is_connected()) {
        iface = 2;
    } else if (wifi_sta_is_connected()) {
        iface = 1;
    }

    if (iotIs.can_publish())
    {
      if (!iotIs.send_data("cr60", cpm, now))
        goto mqtt_publish_fail;
      if (!iotIs.send_data("dr60", usvh, now))
        goto mqtt_publish_fail;
      if (!iotIs.send_data("cr", cr, now))
        goto mqtt_publish_fail;
      if (!iotIs.send_data("dr", dr, now))
        goto mqtt_publish_fail;
      if (!iotIs.send_data("voltage", hv_avg_get(), now))
        goto mqtt_publish_fail;
      if (!iotIs.send_data("samplerate", devCfg.interval, now))
        goto mqtt_publish_fail;
      if (!iotIs.send_data("range", curCh + 1, now))
        goto mqtt_publish_fail;
      if (!iotIs.send_data("iface", iface, now))
        goto mqtt_publish_fail;
    }
    else
    {
      ESP_LOGW(TAG, "MQTT not connected, dropping telemetry batch");
    }
    mqtt_publish_fail:
    ;
  }
}

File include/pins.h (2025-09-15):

#pragma once
#include <Arduino.h>

/**
 * \file
 * \brief Direct I/O helpers and pin map (AVR bit indices, not Arduino pin numbers).
 * \details
 * Defines port bit positions for a flyback/PSU board and provides small inline helpers:
 * - LED control on PC2/PC3
 * - External EN input on PD3
 * - 2-bit range code read on PD4/PD5 (active-low)
 * - Resistor-switch controls on PB6/PB7/PD0/PD1
 *
 * \note All pin macros below are **bit numbers** (e.g., \c PD4 == 4) to be used with
 * DDRx/PORTx/PINx and \c _BV(). They are **not** Arduino digital pin IDs.
 *
 * \warning \c STATUS0 and \c STATUS1 are set to PD4/PD5, which overlap with \c RANGE0/\c RANGE1.
 * If both are intended, reassign to avoid contention.
 */

// --- User pin assignments (bits, not Arduino numbers) ---

/** \brief Gate drive output (bit index on PORTB). */
#define GATE_OUT PB1
/** \brief Feedback input (bit index on PORTC). Typically analog/ADC node. */
#define FB_IN PC0

/** \brief Status line 0 on PORTD.
 *  \warning Overlaps with \c RANGE0 (PD4). */
#define STATUS0 PD4
/** \brief Status line 1 on PORTD.
 *  \warning Overlaps with \c RANGE1 (PD5). */
#define STATUS1 PD5

/** \brief Over-current / analog comparator input (AIN0) on PORTD. */
#define OC_IN PD6 // AIN0 (comparator input)
/** \brief External enable input on PORTD (see EN helpers below). */
#define EN_IN PD3

/** \brief Range select input bit 0 (active-low) on PORTD with pull-up. */
#define RANGE0 PD4
/** \brief Range select input bit 1 (active-low) on PORTD with pull-up. */
#define RANGE1 PD5

/** \brief Green OK LED on PORTC bit 2. */
#define LED_OK PC2
/** \brief Red FAULT LED on PORTC bit 3. */
#define LED_FAULT PC3

/** \brief Resistor-switch output 0 (divider control) on PORTB. */
#define R_SW0 PB6
/** \brief Resistor-switch output 1 on PORTB. */
#define R_SW1 PB7
/** \brief Resistor-switch output 2 on PORTD. */
#define R_SW2 PD0
/** \brief Resistor-switch output 3 on PORTD. */
#define R_SW3 PD1

// --- Port helpers (direct I/O) ---

/**
 * \brief 8-bit variant of \c _BV() for clarity with uint8_t expressions.
 * \param b Bit position (0..7).
 * \return (uint8_t)1U << b
 */
#define _BV8(b) (uint8_t(1U) << (b))

// -----------------------------------------------------------------------------
// LEDs
// -----------------------------------------------------------------------------

/**
 * \brief Drive the OK LED on PC2.
 * \param on \c true turns the LED on (if wired active-high), \c false turns it off.
 * \note Assumes DDRC for PC2 was configured as output elsewhere.
 */
static inline void led_ok_set(bool on)
{
  if (on)
    PORTC |= _BV8(LED_OK);
  else
    PORTC &= ~_BV8(LED_OK);
}

/**
 * \brief Drive the FAULT LED on PC3.
 * \param on \c true turns the LED on (if wired active-high), \c false turns it off.
 * \note Assumes DDRC for PC3 was configured as output elsewhere.
 */
static inline void led_fault_set(bool on)
{
  if (on)
    PORTC |= _BV8(LED_FAULT);
  else
    PORTC &= ~_BV8(LED_FAULT);
}

// -----------------------------------------------------------------------------
// EN (active-low external input on PD3)
// -----------------------------------------------------------------------------

/**
 * \brief Configure PD3 as a plain input for external EN (no internal pull-up).
 * \details
 * - Sets DDRD.PD3 = 0 (input) and clears PORTD.PD3 (disables pull-up).
 * - Clears TCCR2A.COM2B[1:0] to ensure Timer2 isn't driving OC2B on PD3.
 */
static inline void EN_init_input()
{
  // Input, NO internal pull-up (external pulldown).
  DDRD &= ~_BV(PD3);
  PORTD &= ~_BV(PD3); // ensure pull-up is OFF
  // Make sure Timer2 isn't driving OC2B on PD3
  TCCR2A &= ~(_BV(COM2B1) | _BV(COM2B0));
}

/**
 * \brief Read the EN input level.
 * \return \c true if PD3 is high, \c false if low.
 * \note EN is active-high, \c false means "disabled".
 */
static inline bool EN_is_active() { return (PIND & _BV(PD3)) != 0; }

// -----------------------------------------------------------------------------
// Range inputs (1-of-4) on PD4/PD5 with pull-ups (active-low)
// -----------------------------------------------------------------------------

/**
 * \brief Configure PD4 and PD5 as inputs with internal pull-ups for range code.
 */
static inline void range_inputs_init()
{
  DDRD &= ~(_BV8(RANGE0) | _BV8(RANGE1));
  PORTD |= (_BV8(RANGE0) | _BV8(RANGE1)); // pull-ups
}

/**
 * \brief Read the 2-bit range code (active-low).
 * \return Value 0..3 computed as \c (!PD5)<<1 | (!PD4).
 * \note Because of pull-ups, a grounded/low pin reads as 0; inversion yields the code.
 */
static inline uint8_t range_code_read()
{ // 0..3
  uint8_t r0 = (PIND & _BV8(RANGE0)) ? 1 : 0;
  uint8_t r1 = (PIND & _BV8(RANGE1)) ? 1 : 0;
  return (uint8_t)((!r1) << 1 | (!r0)); // active-low to code
}

// -----------------------------------------------------------------------------
// Resistor-divider switches (outputs)
// -----------------------------------------------------------------------------
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

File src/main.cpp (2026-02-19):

#include <Arduino.h>
#include "pins.h"
#include "config_clock.h"

#include "drivers/timebase.h"
#include "drivers/pwm.h"
#include "drivers/adc.h"
#include "drivers/comp.h"
#include "drivers/range.h"
#include "drivers/status_led.h"

#include "control/types.h"
#include "control/controller.h"

#include "cfg/config.h"
#include "comm/i2c_proto.h"

/**
 * \file
 * \brief Firmware entry points: hardware bring-up, main control loop, and UI.
 * \details
 * Responsibilities:
 * - Enforce safe gate state on boot; set CPU prescaler via \c clock_set_div().
 * - Init low-level drivers (PWM, ADC, comparator, timebase) and range IO.
 * - Load configuration (EEPROM with wear leveling) and reset controller state.
 * - Bind and start the I²C slave (addr 0x2A) for config/status access.
 * - Run the 1 kHz control loop, range switching state machine, and LEDs.
 *
 * LED policy (see \c drivers/status_led.*):
 * - Fault LED encodes fault codes (OC/OV, etc.).
 * - OK LED indicates run state (boot, wait EN, precharge, ramp, PFM hold, etc.).
 */

// Shared with comparator ISR
extern volatile uint8_t g_allow_switch; //!< Allows PWM re-enable after OC in next period.

/** \brief Global configuration blob (loaded from EEPROM or defaults). */
static AppConfig g_cfg;
/** \brief Runtime controller state (integrators, latches, EMA, etc.). */
static ControlState g_state;

extern uint8_t i2c_get_range_src();
extern void i2c_set_range_src(uint8_t src);

static uint32_t last_i2c_select_us = 0;
static const uint32_t I2C_HOLD_US = 0; // set to e.g. 30*1000000 for AUTO fallback after 30 s

/**
 * \brief Arduino setup: put hardware in a safe state and initialize all subsystems.
 * \details
 * Steps:
 * 1) Force gate LOW and detach OC1A.
 * 2) Apply CPU prescaler (\c CPU_DIV_LOG2 → \c F_CPU_CFG).
 * 3) Configure LEDs, EN input, range IO, and a board strap.
 * 4) Initialize PWM/ADC/comparator/timebase (interrupt-safe).
 * 5) Load configuration; reset controller timebase/phase.
 * 6) Arm comparator after delay (AREF settle), then start I²C at 0x2A.
 */
void setup()
{
  cli();
  // Force gate LOW and detach timer output
  DDRB |= _BV(PB1);                       // PB1 as output
  PORTB &= ~_BV(PB1);                     // drive LOW
  TCCR1A &= ~(_BV(COM1A1) | _BV(COM1A0)); // detach OC1A from Timer1
  sei();

  clock_set_div(CPU_DIV_LOG2);

  // LEDs
  DDRC |= _BV(LED_OK) | _BV(LED_FAULT);
  led_init();

  // EN + ranges
  EN_init_input();
  range_init();

  // I2C
  i2c_bind(&g_cfg, &g_state);
  i2c_init(0x2A); // slave addr

  _delay_ms(3000);

  noInterrupts();
  pwm_init();
  adc_init();
  comp_init();
  timebase_init_us();
  interrupts();

  // Config
  bool loaded = config_load(g_cfg);
  controller_reset(g_state, us_now32());

  // Arm OC later & settle AREF
  comp_arm_after_us(80000UL, us_now32());
  uint32_t t0 = us_now32();
  while (us_now32() - t0 < 100000UL)
  { /* settle */
  }

  (void)loaded;
}

/**
 * \brief Main loop: gating, range handling, control step, and LED/UI updates.
 * \details
 * - EN gating: controller runs only if EN is active and range sequencer is idle.
 * - External range inputs trigger a safe break→wait-stable→make sequence.
 * - Controller executes 1 kHz steps with OV/OC handling and optional PFM hold.
 * - OC sticky pulses extend the OC indicator for UI visibility.
 * - LEDs reflect current run/fault states.
 */
void loop()
{
  uint32_t now = us_now32();

  // --- arbitration state (persist across calls) ---
  static uint32_t last_i2c_select_us = 0;
  static uint8_t last_hw_code = 0xFF;
  static uint8_t last_made = 0xFF;
  const uint32_t I2C_HOLD_US = 0; // >0 to AUTO-fallback to HW after idle; 0 = disabled

  // ---- source selection: HW vs I2C (0x21) ----
  uint8_t src = i2c_get_range_src();

  // I2C range requests (only if not forced-HW)
  uint8_t req;
  if ((src != RANGE_SRC_HW) && i2c_take_range_request(&req))
  {
    last_i2c_select_us = now;
    if (!range_is_busy())
      range_request((uint8_t)(req & 0x03));
    if (src == RANGE_SRC_AUTO)
      i2c_set_range_src(RANGE_SRC_I2C); // I²C takes over
  }

  // Optional AUTO fallback to HW after inactivity
  if (src == RANGE_SRC_AUTO && I2C_HOLD_US > 0)
  {
    if ((int32_t)(now - last_i2c_select_us) >= (int32_t)I2C_HOLD_US)
    {
      i2c_set_range_src(RANGE_SRC_HW);
      src = RANGE_SRC_HW;
    }
  }

  // HW pins drive range only in HW mode
  if (src == RANGE_SRC_HW)
  {
    uint8_t hw = range_get_input_code();
    if (hw != last_hw_code && !range_is_busy())
    {
      range_request((uint8_t)(hw & 0x03));
      last_hw_code = hw;
    }
  }

  // ---- EN gating computed AFTER arbitration ----
  bool allow = EN_is_active() && !range_is_busy();
  g_allow_switch = allow;
  comp_service(now);

  // Controller inputs
  uint16_t fb_raw = adc_fb_decim();

  if (!allow)
  {
    // Keep gate off but continue the range FSM
    pwm_disable();
    pwm_set_duty(0.0f);
    range_service(now, fb_raw, 0);

    // Apply per-range ACTIVE profile when relay makes
    uint8_t made = range_get_current_code();
    if (made != last_made && made < 4)
    {
      last_made = made;
      g_cfg.ctrl.fb_set_cnt = g_cfg.ctrl.fb_set_cnt_tab[made];
      g_cfg.ctrl.fb_ov_trip_cnt = g_cfg.ctrl.fb_ov_trip_cnt_tab[made];
      g_cfg.ctrl.fb_ov_clear_cnt = g_cfg.ctrl.fb_ov_clear_cnt_tab[made];
      g_state.active_range = made;

      // gentle re-entry
      g_state.ramp_ms = 0;
      g_state.pre_ms = 0;
      g_state.phase = PH_PRECHARGE;
    }

    led_status_run(now, range_is_busy() ? S_RANGE_SWITCH : S_WAIT_EN);
    led_fault_run(now, F_NONE);
    return;
  }

  // ---- Normal control path ----
  uint16_t fb;
  int16_t dcounts;
  uint8_t oc_now = comp_oc_fault();
  controller_step(now, g_cfg.ctrl, g_state, fb_raw, oc_now, allow, fb, dcounts);

  uint8_t oc_event = comp_oc_pulse_sticky();
  if (oc_event)
    g_state.oc_latch_ms = 1500;

  // Advance range FSM with real derivative (stability check meaningful)
  range_service(now, fb, dcounts);

  // Apply per-range ACTIVE profile when relay makes
  uint8_t made = range_get_current_code();
  if (made != last_made && made < 4)
  {
    last_made = made;
    g_cfg.ctrl.fb_set_cnt = g_cfg.ctrl.fb_set_cnt_tab[made];
    g_cfg.ctrl.fb_ov_trip_cnt = g_cfg.ctrl.fb_ov_trip_cnt_tab[made];
    g_cfg.ctrl.fb_ov_clear_cnt = g_cfg.ctrl.fb_ov_clear_cnt_tab[made];
    g_state.active_range = made;

    // restart gently after relay change
    g_state.ramp_ms = 0;
    g_state.pre_ms = 0;
    g_state.phase = PH_PRECHARGE;
    pwm_disable();
  }

  // ---- LEDs ----
  FaultCode fcode = F_NONE;
  RunState rstate = S_WAIT_EN;

  if (g_state.ov_fault)
  {
    fcode = F_OV;
    rstate = S_RAMP;
  }
  else if (g_state.oc_latch_ms)
  {
    fcode = F_OC;
    rstate = S_RAMP;
  }
  else if (g_state.phase == PH_PRECHARGE)
  {
    rstate = S_PRECHARGE;
  }
  else if (g_state.burst_skip)
  {
    rstate = S_BURST_HOLD;
  }
  else if (pwm_get_duty() > 0.0f)
  {
    rstate = S_REGULATING;
  }
  else
  {
    rstate = S_RAMP;
  }
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

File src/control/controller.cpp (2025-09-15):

#include <math.h>
#include "controller.h"
#include "drivers/pwm.h"

/**
 * \file
 * \brief Closed-loop controller implementation for flyback HV supply.
 * \details
 * Implements:
 * - Default parameter initialization (\c controller_init_defaults)
 * - Runtime state reset (\c controller_reset)
 * - 1 kHz control step combining PRECHARGE, PI(+Dmeas), and a silent PFM "microburst" mode (\c controller_step)
 *
 * **Units and conventions**
 * - Time: microseconds for scheduler period, milliseconds for ramps/cooldowns.
 * - Duty: fractional 0..1; quantized to timer resolution via \c pwm_min_step().
 * - Feedback (FB): ADC counts (e.g., 10-bit 0..1023). \c fb_set_cnt is the target.
 * - Derivative output: \c dcounts_out in raw counts per control step (~counts/ms at 1 kHz).
 * - Over-voltage (OV) latch: trips above \c fb_ov_trip_cnt, clears below \c fb_ov_clear_cnt.
 * - Over-current (OC) is provided by the caller as a latched/instantaneous flag.
 *
 * **Phases**
 * - \c PH_PRECHARGE : soft start at fixed small duty until either time elapses or FB reaches a fraction
 *   of the ramped setpoint.
 * - \c PH_PI : main PWM control loop with PI + filtered derivative feedback.
 *
 * **PFM microburst mode**
 * - After ramp completion, if FB is close to setpoint (\c pfm_enter_sub_cnt) the loop switches to a
 *   low-audibility scheme: short PWM "microbursts" of small duty followed by a randomized cooldown
 *   (\c pfm_min_off_ms ± jitter). This reduces audible noise and average power when near target.
 */

// ---- helpers ----------------------------------------------------------------

/**
 * \brief Clamp helper for floats.
 * \param x Value.
 * \param lo Lower bound (inclusive).
 * \param hi Upper bound (inclusive).
 * \return \c x limited to [lo, hi].
 */
static inline float clampf(float x, float lo, float hi)
{
  return (x < lo) ? lo : (x > hi) ? hi
                                  : x;
}

// ---- API --------------------------------------------------------------------

/**
 * \brief Initialize controller parameters with safe, production-friendly defaults.
 * \param[out] c Parameter block to populate.
 * \details
 * - 1 kHz control loop (\c control_period_us = 1000).
 * - Soft ramp, short precharge at very low duty.
 * - Conservative PWM caps and step slew to avoid audible artifacts.
 * - PI gains and leaky integrator to minimize windup.
 * - PFM microburst defaults enabled (exact thresholds set via configuration in counts).
 * \note Derivative term uses a simple 1st-order IIR with \c deriv_alpha.
 */
void controller_init_defaults(ControlParams &c)
{
  // timing
  c.control_period_us = 1000; // 1 kHz control loop
  c.ramp_time_ms = 1500;
  c.precharge_time_ms = 200;
  c.precharge_duty = 0.015f;
  c.precharge_exit_frac = 0.85f;

  // gains
  c.KP = 0.00045f;
  c.KI = 0.000006f;
  c.KD = 0.00018f;
  c.deriv_alpha = 0.05f;

  // PWM limits (ramp/PI only)
  c.duty_abs_max = 0.20f;  // absolute safety (driver also clamps)
  c.duty_ramp_cap = 0.12f; // ≤12% during ramp/PI
  c.duty_post_cap = 0.12f; // ≤12% steady PWM
  c.duty_step_max = 0.0008f;
  c.i_leak = 0.9995f;

  // deadband
  c.err_deadband_cnt = 0;

  // PFM (microburst) hold — set exact counts in cfg
  c.pfm_enable = 1;
  c.pfm_min_off_ms = 300;  // long cooldown = very low average pps
  c.pfm_lo_sub_cnt = 0;    // e.g., counts_from_volts(8–12 V) in cfg
  c.pfm_enter_sub_cnt = 0; // e.g., counts_from_volts(12–15 V) in cfg

  // microburst shape (inaudible)
  c.pfm_burst_ms = 3;       // 2–4 ms of 31.25 kHz PWM
  c.pfm_burst_duty = 0.03f; // ~3% duty during microburst (cap still applies)

  // oneshot fields kept for compatibility (unused here)
  c.pfm_ton_us = 0;
}

/**
 * \brief Reset dynamic controller state.
 * \param[out] s  State block to reset.
 * \param now_us  Current timestamp in microseconds (used to seed scheduler).
 * \details
 * Clears latches, integrators, filters, ramps; sets phase to \c PH_PRECHARGE and marks OV as faulted
 * (requires below-clear threshold to unlatch).
 */
void controller_reset(ControlState &s, uint32_t now_us)
{
  s.last_us = now_us;
  s.ramp_ms = 0;
  s.pre_ms = 0;

  s.duty = 0.0f;
  s.integ = 0.0f;

  s.fb_prev = 0;
  s.d_filt = 0.0f;
  s.d_inited = 0;

  s.burst_skip = 0;
  s.burst_off_ms = 0;   // re-used as PFM cooldown
  s.pfm_mb_ms_left = 0; // microburst time remaining

  s.ov_fault = 1;
  s.oc_latch_ms = 0;

  s.fb_ema = 0;
  s.fb_ema_inited = 0;

  s.phase = PH_PRECHARGE;
}

/**
 * \brief Execute one control iteration (nominally every \c control_period_us).
 * \param now           Current timestamp in microseconds (monotonic).
 * \param[in]  c        Tunable control parameters (constant during step).
 * \param[in,out] s     Controller state (integrators, latches, phase, etc.).
 * \param fb_raw        Latest raw feedback (ADC counts).
 * \param oc_now        Over-current flag (non-zero means fault this step).
 * \param allow_switch  If \c false, PWM is disabled regardless of state/faults.
 * \param[out] fb_out   EMA-filtered feedback (counts) exported to caller.
 * \param[out] dcounts_out  First-difference derivative (counts/step, ~counts/ms @1 kHz).
 * \details
 * - 1-tap EMA on \c fb_raw, alpha=1/8.
 * - OV latch and OC handling gate the state machine and force PWM off.
 * - Scheduler enforces 1 kHz; if called early, it returns immediately.
 * - When ramp done and near setpoint, uses PFM microbursts; otherwise PRECHARGE → PI(+D) PWM.
 * - Duty is quantized to the PWM grid and slewed by \c duty_step_max to avoid audible jumps.
 * - Integrator uses leak factor \c i_leak and conditional anti-windup against saturation.
 * \note Requires timer/PWM backend: \c pwm_min_step(), \c pwm_set_duty(), \c pwm_enable_sync_bottom(),
 * \c pwm_disable(), \c pwm_is_enabled().
 */
void controller_step(uint32_t now,
                     ControlParams &c,
                     ControlState &s,
                     uint16_t fb_raw,
                     uint8_t oc_now,
                     bool allow_switch,
                     uint16_t &fb_out,
                     int16_t &dcounts_out)
{
  // === EMA (alpha = 1/8) ===
  if (!s.fb_ema_inited)
  {
    s.fb_ema = fb_raw;
    s.fb_ema_inited = 1;
  }
  s.fb_ema += ((int32_t)fb_raw - (int32_t)s.fb_ema) >> 3;
  uint16_t fb = (uint16_t)s.fb_ema;
  fb_out = fb;

  // Helpers
  const float DLSB = pwm_min_step(); // ≈0.39% at 31.25 kHz
  const float Q_EPS = 1e-9f;
  auto quant = [&](float d) -> float { // quantize to PWM grid
    float q = roundf(d / DLSB) * DLSB;
    if (q < 0.0f)
      q = 0.0f;
    return q;
  };

  // === OV latch ===
  if (fb > c.fb_ov_trip_cnt)
    s.ov_fault = 1;
  if (s.ov_fault && fb < c.fb_ov_clear_cnt)
    s.ov_fault = 0;

  // OC latch visibility (LED/UI)
  if (oc_now)
  {
    s.oc_latch_ms = 1500;
  }
  else if (s.oc_latch_ms)
  {
    --s.oc_latch_ms;
  }

  // === 1 kHz scheduler ===
  if ((uint32_t)(now - s.last_us) < c.control_period_us)
  {
    dcounts_out = 0;
    return;
  }
  s.last_us += c.control_period_us;
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

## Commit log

2025-08-17 Working PWM
2025-09-12 Update LED signaling
2025-12-14 Add pcb
    [5-535541-8_TYC.step, Coilcraft-GA3460-BL.step, RLA4_SHV_SME.step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]
2025-12-25 Separate CPM for each channel Fix storage Enable commands from iSDG
    [flyback.cpp, geiger_counter.c, main.cpp]
2026-03-25 Reduce filtering
2026-04-01 Update PCNT filter to 500ns
2026-04-23 Fix bootloop when wifi is not present
    [main.cpp]
2026-04-23 Fix MQTT related bugs
    [main.cpp]
2026-04-23 Fix job bugs, add IF sensor
    [main.cpp]
